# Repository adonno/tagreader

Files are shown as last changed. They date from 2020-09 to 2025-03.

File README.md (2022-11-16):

<a href="https://www.buymeacoffee.com/adonno" target="_blank">Buy Me A Coffee</a>



# Tag Reader for Home Assistant

The tag reader is a simple to build/use NFC tag reader, specially created for [Home Assistant](https://www.home-assistant.io). It is using a D1 mini ESP 8266 and the PN532 NFC module. The firmware is built using [ESPhome](https://www.esphome.io).

> I am selling a pre-built version, a DIY version (assembly required), or just the case (use with own components). Check it out on [my website](https://adonno-crafts.myshopify.com/).

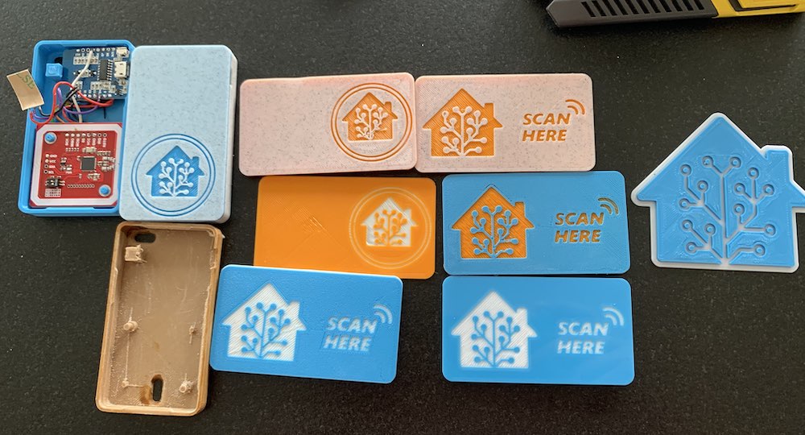
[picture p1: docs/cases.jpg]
Photos of the final product


## Building the tag reader

To build your own tag reader, you need the following components:

 - [ESP8266 D1 Mini](https://s.click.aliexpress.com/e/_d8l72oB)  
 - [PN532 NFC Reader](https://s.click.aliexpress.com/e/_dZNORIJ)
 - [WS2812](https://s.click.aliexpress.com/e/_d82GRqr)
 - [Buzzer](https://s.click.aliexpress.com/e/_dZ5F5yj)

The 3D models for the case are [here](STLs).

~~**WARNING** regarding AZdelivery D1. We have had several users contacting us with different issues, we don't recommend using these boards and won't provide support for them.~~  
Recent reports suggest more clones of the D1 are now working as expected. This has been verified on an AZdelivery D1.

### Connecting the components

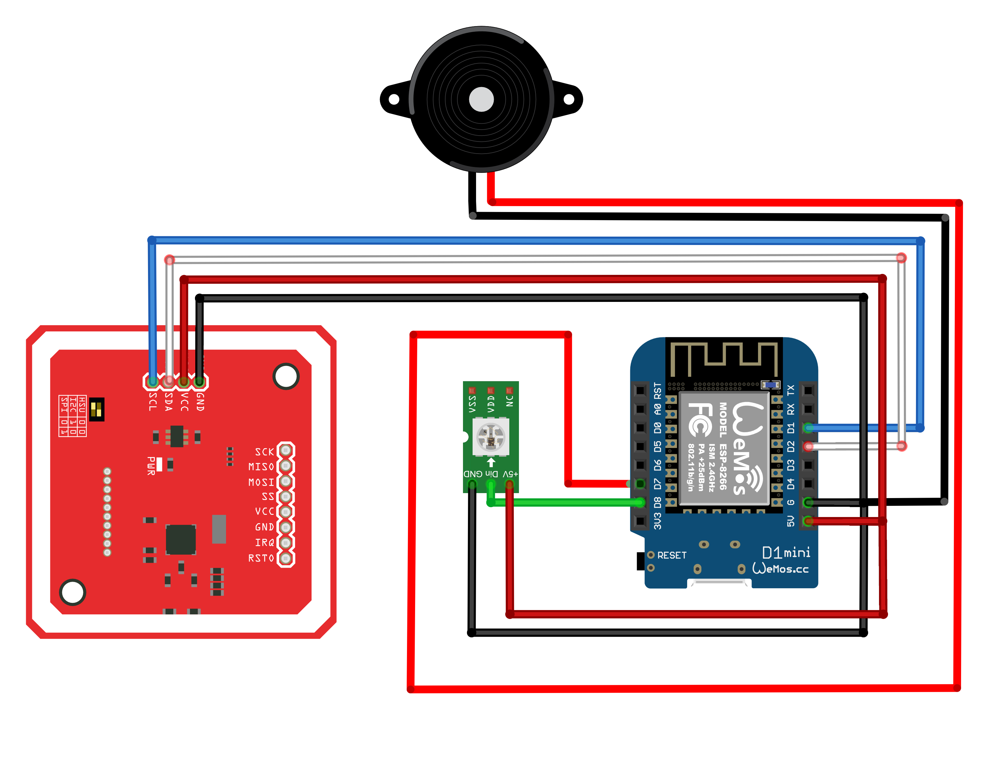
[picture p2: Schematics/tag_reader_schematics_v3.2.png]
Photo of schematics


There are not too many components to connect, but it does require soldering. You will need the following:

- [Solder](https://s.click.aliexpress.com/e/_dT3S62j)
- [Soldering iron with a fairly thin tip](https://s.click.aliexpress.com/e/_dXaI6nz)
- [About 40cm of thin wire (at least 5 different colors)](https://s.click.aliexpress.com/e/_dZvoYoB)

Also, make sure that you have set the switches on the PN532 to the following:
- Switch 1: On (up)
- Switch 2: Off (down)

This enables the PN532 module to communicate with the D1 over I2C, and is required for the modules to work together!

To flash the reader firmware to your D1 Mini you point ESPHome at [tagreader.yaml](tagreader.yaml).  
> :warning: The tag reader requires ESPHome `1.16.0`.

If you're new to ESPHome, we recommend that you use the [ESPHome Home Assistant add-on](https://esphome.io/guides/getting_started_hassio.html).

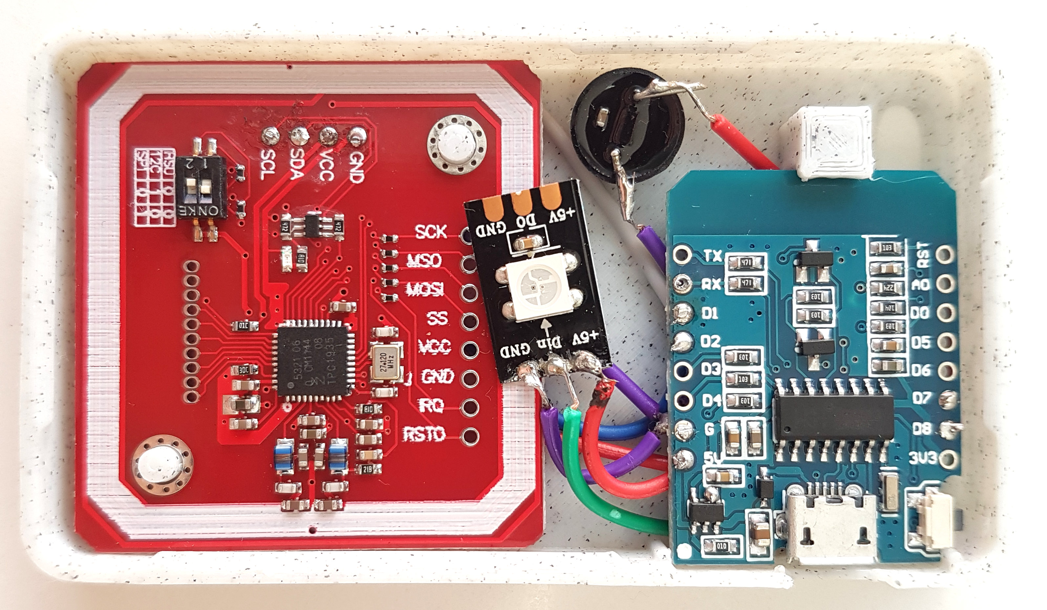
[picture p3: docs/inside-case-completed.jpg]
Open Case


## Configuring for use with Home Assistant

The tag reader requires [Home Assistant](https://www.home-assistant.io) 0.115 or later.

If the tag reader is unable to connect to a wifi network, it will start a WiFi access point with a captive portal to allow you to enter your WiFi credentials.

The tag reader will be automatically discovered by Home Assistant once the tag reader is connected to the same network. You can follow the instructions in the UI to set it up.

## Usage

Scanned tags can be managed from the tags interface in Home Assistant. You can find it under config -> tags.

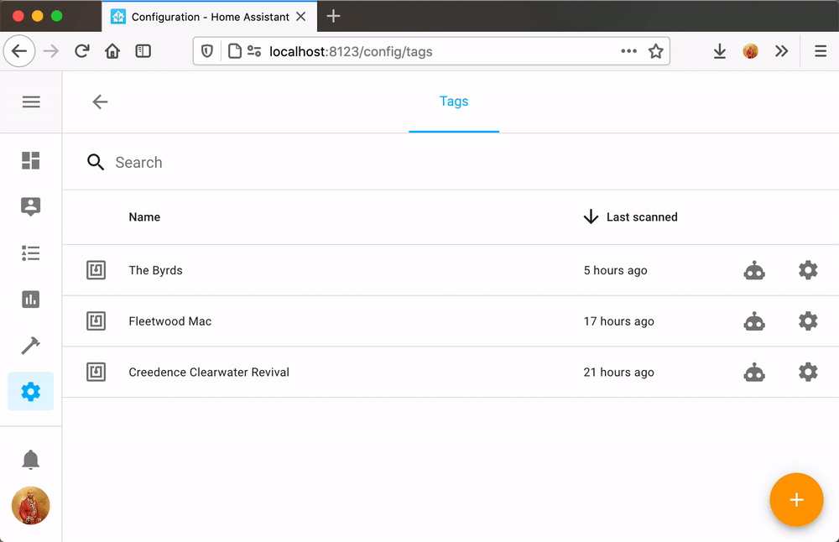
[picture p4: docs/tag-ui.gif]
Screenshot of the Home Assistant tag UI


## Disclamer

We use aliexpress affiliate links for the components and the tools. Some Ad-blockers might block these links and thus they seem to appear broken. You will have to temporarily disable the ad-blocker to open these links.

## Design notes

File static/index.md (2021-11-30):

<a href="https://www.buymeacoffee.com/adonno" target="_blank">Buy Me A Coffee</a>



# Tag Reader for Home Assistant

The tag reader is a simple to build/use NFC tag reader, specially created for [Home Assistant](https://www.home-assistant.io). It is using  the PN532 NFC module. The firmware is built using [ESPhome](https://www.esphome.io).

The Reader works on the 13.56Mhz (NTAG 213) Frequency. 

> You can buy a prebuild version at https://shop.adonno.com

## Installation

You can use the button below to install the firmware directly to your device via USB from the browser.

<esp-web-install-button manifest="./manifest.json"></esp-web-install-button>

<script type="module" src="https://unpkg.com/esp-web-tools@5.2.0/dist/web/install-button.js?module"></script>

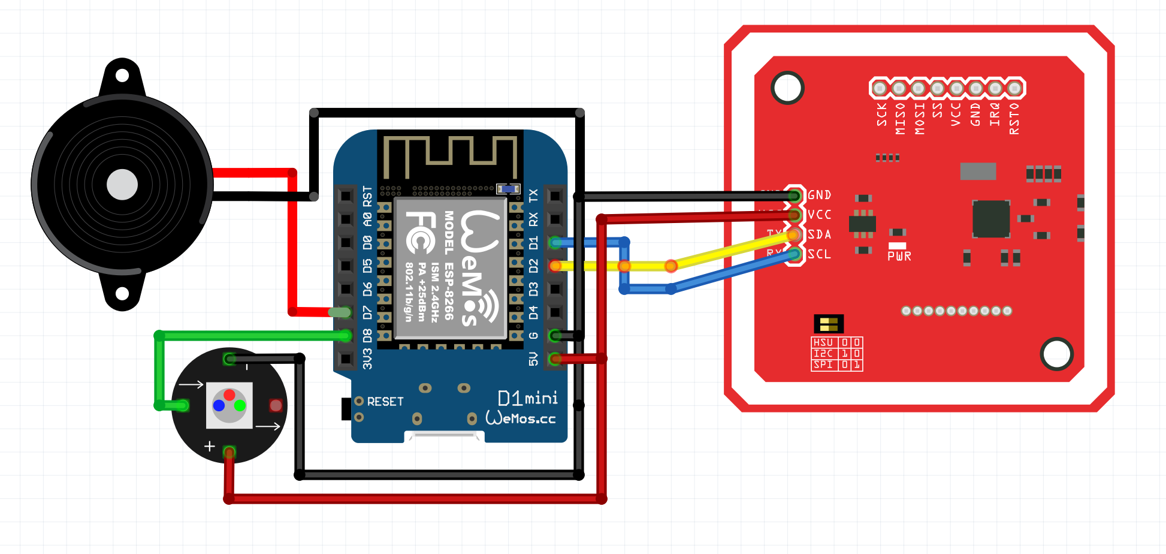
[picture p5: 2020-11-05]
Schematics/tag_reader_schematics_v2.png

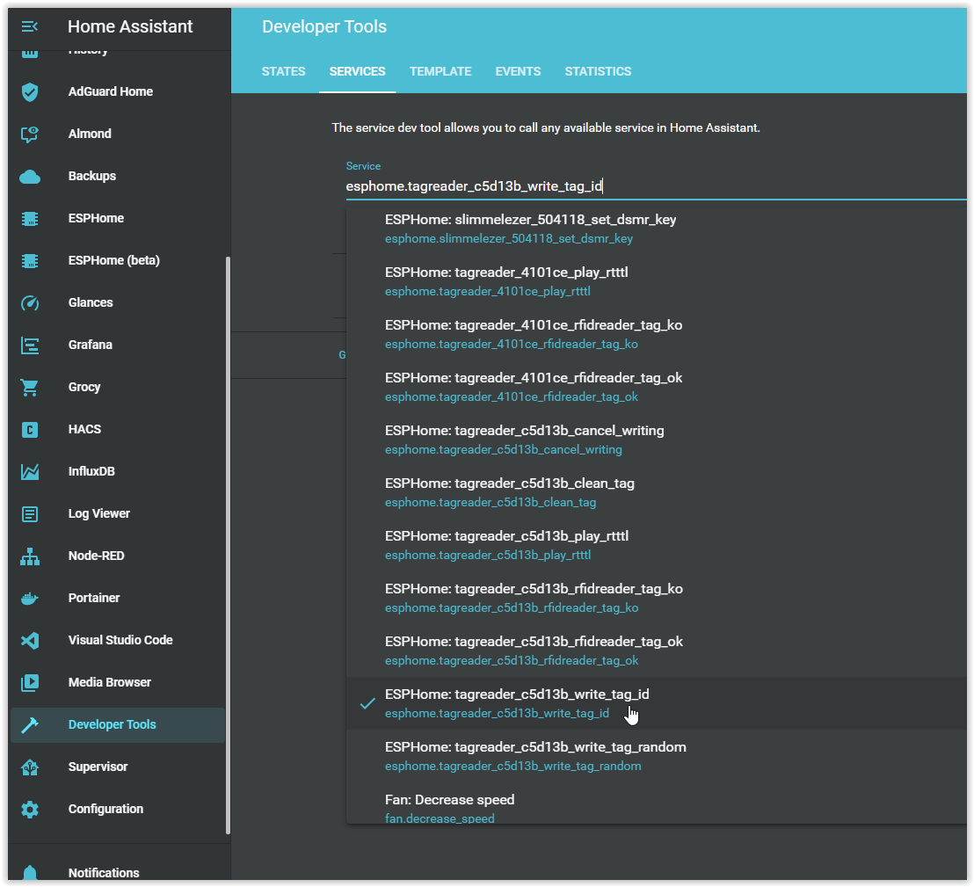
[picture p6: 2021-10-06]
docs/tagreader_services.PNG

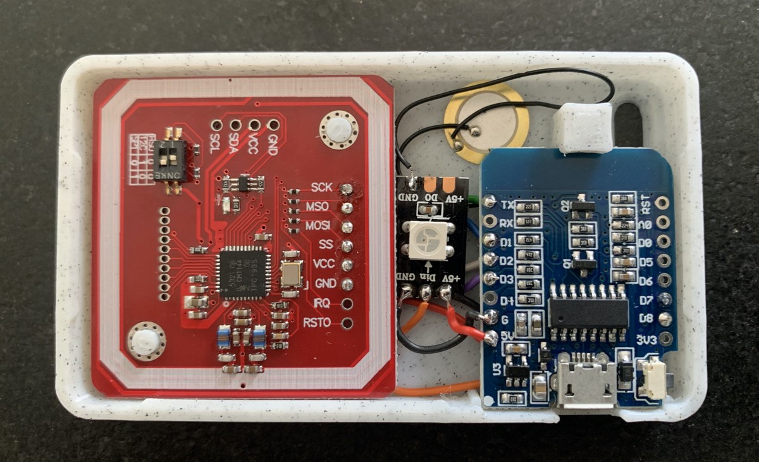
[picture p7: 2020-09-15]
docs/open-case.jpg

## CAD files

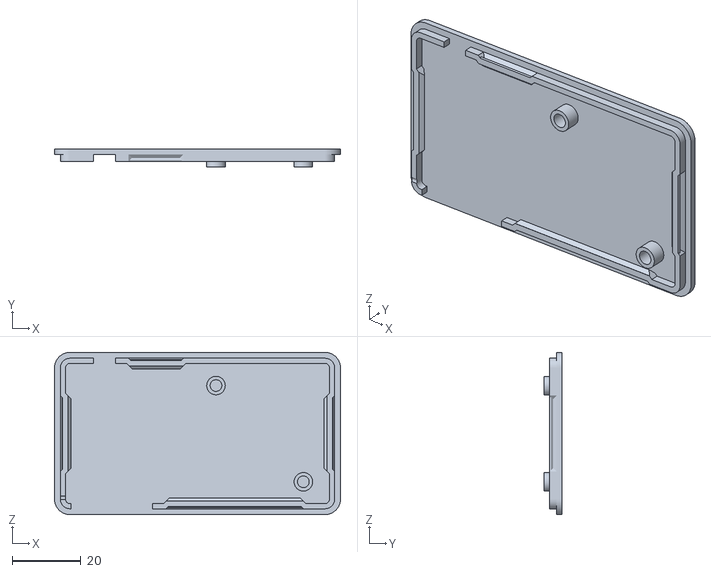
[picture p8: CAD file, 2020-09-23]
STLs/Cover-circles_no_logo.stl
83.2 x 5.10 x 47.2

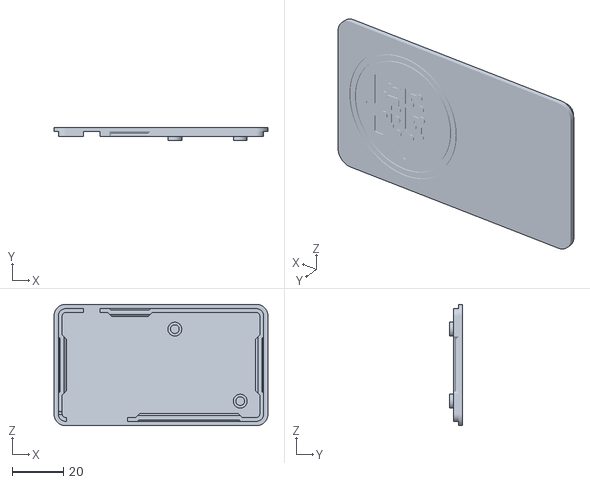
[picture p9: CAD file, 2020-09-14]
STLs/Cover-circles_horizontal.stl
83.2 x 5.10 x 47.2

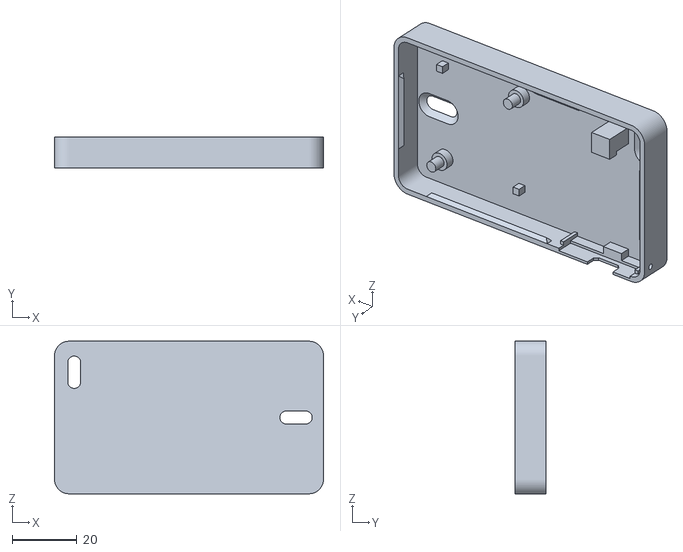
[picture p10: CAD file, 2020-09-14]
STLs/Case-2.stl
83.2 x 9.50 x 47.2

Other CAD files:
STLs/Cover-circles_vertical.stl
STLs/Cover-scan_herel.stl

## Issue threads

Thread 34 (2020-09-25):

D1 Mini won't boot with PN532 power connected

sevlitfest, 2020-09-25:
Initially had same issue on a NodeMCU - then realised it was underpowered for the PN532.
Switched to a D1 Mini - but same, it won't boot to ESP Home when the power is connected.
Boots in fine when Power and GND disconnected - but then obviously can't wake the PN532

Any ideas?

Checked Cables and Pins.

adonno, 2020-09-27:
yeah, we noticed that the PN532 might be messing with the D1. So we (actually @jesserockz ) are currently working on a new version based on I2C that should solve the issue.

lubbertkramer, 2020-09-29:
Any idea for a workaround in the time being?

tdroza, 2020-09-29:
I've been battling with this issue for days! So glad it's not just me! I can see in debug from the D1 that it boots, scans for wifi, attempts to connect then resets the wifi and starts again. Very occasionally it will connect to wifi but then doesn't connect to ESPHome (I'm using the Home Assistant plugin on an RPi 4). I had to remove the `baud:` option from the logger to get log output from the D1 over USB.

I even tried 2 different pn532 boards and about 4 different D1 Minis! I've tried powering the PN532 separately (not from the D1) but get the same issue. I can see tags being scanned in the D1 log output, but obviously Home Assistant doesn't receive an event because the D1 isn't connected. I've stripped down my yaml to remove everything but the SPI and PN532 but no luck. As soon as I disconnect the PN532 the D1 will immediately connect to WiFi.

I considered trying to set it up to use I2C but wasn't sure if it would work. I might give that a go myself while waiting for the updated version.

adonno, 2020-09-29:
@tdroza I2C won't work, for now, @jesserockz is currently working on a new library and is investing a lot of work in this. I would suggest being patient since I don't want to come up with "half" solutions. But yeah we are coming with I2C. SPI is having too many issues and messing with WIFI. I will check with Jessee if we can post a binary for tests

tdroza, 2020-09-29:
Ah ok thanks for the update @adonno. I've got my D1 Mini and PN532 on a breadboard at the moment so if you want me to test any binaries give me a shout as I can change the wiring quickly.

jesserockz, 2020-09-29:
Hello, we have been trying out using I2C, (alongside with some changes to read the NDEF formatted cards that the mobile apps can write to) in #45. You can rewire for I2C and give that PR/branch a try and let us know.
Thanks

sevlitfest, 2020-10-16:
Just tried the new #45 and sadly still have the same issue where ESPHome doesnt seem to boot with the reader connected.
Included the ndef.h and updated the yaml but no joy :(

jesserockz, 2020-10-16:
@sevlitfest can you try #52 please?
Also does it boot if you remove the pn532 lines from yaml, but have the board attached still?

OliPassey, 2020-10-17:
I'm getting errors when trying to compile the new tagreader.yaml in ESPHome.
Using ESPHome 1.15.2
I don't believe im using an AZDelivery D1 Mini - the board has wemos.cc v3.0.0 D1 Mini Printed on it.

When the  ESPHome is first built, with no config and the PN532 connected, it boots fine.

Current compiling error:
`INFO Reading configuration /config/tagreader.yaml...
Failed config

api: [source /config/tagreader.yaml:48]
  services:  [source /config/tagreader.yaml:49]
    - service: rfidreader_tag_ok
      then:
        - rtttl.play: beep:d=16,o=5,b=100:b
    - service: rfidreader_tag_ko
      then:
        - rtttl.play: beep:d=8,o=5,b=100:b
    - service: play_rtttl
      variables:
        song_str: string
      then:
        - rtttl.play: !lambda |-
            return song_str;
    - [source /config/tagreader.yaml:63]
      service: write_tag_random
      variables:
        continuous: bool
      then:  [source /config/tagreader.yaml:67]
        - lambda: id(continous_writing_mode) = continuous;
        - [source /config/tagreader.yaml:68]
          while:  [source /config/tagreader.yaml:69]
            condition:
              lambda: return id(continous_writing_mode);
            then:  [source /config/tagreader.yaml:72]
              - lambda: |-
                  static const char alphanum[] = "0123456789abcdef";
                  std::string uri = "https://www.home-assistant.io/tag/";
                  for (int i = 0; i < 8; i++)
                    uri += alphanum[random_uint32() % (sizeof(alphanum) - 1)];
                  uri += "-";
                  for (int j = 0; j < 3; j++) {
                    for (int i = 0; i < 4; i++)
                      uri += alphanum[random_uint32() % (sizeof(alphanum) - 1)];
                    uri += "-";
                  }
                  for (int i = 0; i < 12; i++)
                    uri += alphanum[random_uint32() % (sizeof(alphanum) - 1)];
                  auto message = new nfc::NdefMessage();
                  message->add_uri_record(uri);
                  ESP_LOGD("tagreader", "Writing payload: %s", uri.c_str());
                  id(pn532_board).write_mode(message);
              - [source /config/tagreader.yaml:89]
        
                Unable to find condition with the name 'pn532.is_writing'.
                wait_until:  [source /config/tagreader.yaml:90]
                  not:
                    pn532.is_writing:
    - service: write_tag_id
      variables:
        tag_id: string
      then:
        - globals.set:
            id: continous_writing_mode
            value: false
        - lambda: |-
            auto message = new nfc::NdefMessage();
            std::string uri = "https://www.home-assistant.io/tag/";
            uri += tag_id;
            message->add_uri_record(uri);
            id(pn532_board).write_mode(message);
    - service: clean_tag
      then:
        - globals.set:
            id: continous_writing_mode
            value: false
        - lambda: id(pn532_board).clean_mode();
    - service: cancel_writing
      then:
        - globals.set:
            id: continous_writing_mode
            value: false
        - lambda: id(pn532_board).read_mode();
pn532_i2c: [source /config/tagreader.yaml:136]

  Component not found: pn532_i2c.
  id: pn532_board
  on_tag:
    then:
      - homeassistant.tag_scanned: !lambda |-
          if (!tag.has_ndef_message()) {
            ESP_LOGD("tagreader", "No NDEF");
            return x;
          }
          auto message = tag.get_ndef_message();
          auto records = message->get_records();
          for (auto &record : records) {
            std::string payload = record->get_payload();
            size_t pos = payload.find("https://www.home-assistant.io/tag/");
            if (pos != std::string::npos) {
              return payload.substr(pos + 34);
            }
          }
          ESP_LOGD("tagreader", "Bad NDEF, fallback to uid");
          return x;
      - if:
          condition:
            switch.is_on: buzzer_enabled
          then:
            - rtttl.play: success:d=24,o=5,b=100:c,g,b
      - if:
          condition:
            switch.is_on: led_enabled
          then:
            - light.turn_on:
                id: activity_led
                brightness: 100%
                red: 0%
                green: 100%
                blue: 0%
                flash_length: 500ms`

OliPassey, 2020-10-17:
I think i've got a USB to Serial UART thing around here somewhere, but not sure if / how it would be any use.
But could i use it to get at logs whilst it's hanging? Or do you already know what the issue may be?

jesserockz, 2020-11-05:
@OliPassey / @sevlitfest Please look at #60 and flash using the esphome `dev` branch

OliPassey, 2020-11-05:
Thanks, i'll give it a test
Much appreciated

OliPassey, 2020-11-05:
@jesserockz - I get further with this one, it boots, i get the buzzer tone as it boots, but it doesnt read any tags.
Nothing in the log other than connected successfully.

INFO Reading configuration /config/tagreader1.yaml...
INFO Starting log output from tagreader1.local using esphome API
INFO Connecting to tagreader1.local:6053 (10.0.0.109)
INFO Successfully connected to tagreader1.local

I'm using ESPHome Dev
Devices have turned up in  HA, LED and Buzzer works but Tag says unavailable.

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

adonno, 2020-11-05:
@OliPassey would you mind taking a picture of your PN532 wiring as well as the jumper settings?

OliPassey, 2020-11-05:
How should the jumper settings be set?
I've tried a few variations, so possibly not in the right position currently.

https://photos.app.goo.gl/roMDHmvJ9qnbHnEe8
Whilst some of the soldering isn't great, i don't have any shorts and all connections are secure.

adonno, 2020-11-05:
Ok please invert the Jumpers
1 on (up)
2 off (down)
restart And you should be fine

OliPassey, 2020-11-05:
Still no joy im afraid.

adonno, 2020-11-05:
What did you flash the ESP with ?
In case you used ESPHome flasher please click on "show logs" while having the D1 connected  and then hit the reset button
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

OliPassey, 2020-11-05:
Using 'COM10' as serial port.
Showing logs:
[14:15:30];d[I][logger:166]: Log initialized
[14:15:30][C][ota:366]: There have been 0 suspected unsuccessful boot attempts.
[14:15:30][I][app:029]: Running through setup()...
[14:15:30][C][esp8266_pwm:017]: Setting up ESP8266 PWM Output...
[14:15:30][C][fastled:010]: Setting up FastLED light...
[14:15:30][C][light:097]: Setting up light 'TagReader1 LED'...
[14:15:30][D][light:265]: 'TagReader1 LED' Setting:
[14:15:30][D][light:278]:   Brightness: 100%
[14:15:30][D][light:287]:   Red=100%, Green=100%, Blue=100%
[14:15:30][C][pn532:027]: Setting up PN532...
[14:15:31][W][i2c:070]: Received NACK on transmit of address 0x24
[14:15:33][W][i2c:086]: Requesting 1 bytes from 0x24 failed!
[14:15:33][E][pn532:031]: Error sending version command
[14:15:33][E][component:092]: Component was marked as failed.
[14:15:33][D][binary_sensor:034]: 'TagReader1 Status': Sending initial state OFF

Just looking to see if i have another reader i can try with.

OliPassey, 2020-11-05:
I dont have another unit to test on, does the above suggest dead hardware or something else?

adonno, 2020-11-06:
Not sure but it means that the D1 isn't communicating with the PN532, check your soldering?  Resolder everything, sometimes it's something really small.
BTW LED and buzzer are not necessary for it to work.

Closed 2020-11-05.

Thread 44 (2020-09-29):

Unstable WiFi connection

tipofthesowrd, 2020-09-29:
The WiFi connection of the esp8266 to the network is unstable.
When connecting the pn532 module and after the setup of the module the WiFi connection and connection to the API stops & hangs often as evidenced by missing pings.

When the module is (physically) connected in HSU mode (or not setup) the connection is stable.

gadgetshed, 2020-09-29:
I can concur that the network connection is very flaky and it seems to drop off the network frequently.

gadgetshed, 2020-09-29:
I'm running a spi and i2c version next to each other and the i2c version is very stable in comparison so it's definitely the way to go.

As an aside the new schematic has the buzzer on D7 but the yaml is on D3 so I'm using D3 for wiring.

tipofthesowrd, 2020-09-29:
Where can I find the i2c version? Esphome didn't seem to have it in the
docs?

Op di 29 sep. 2020 21:14 schreef Steve Cooper <notifications@github.com>:

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

jesserockz, 2020-09-29:
@tipofthesowrd #45

tipofthesowrd, 2020-09-30:
I tried the i2c version, altough I see some improvement, there seem to be some other issues (see below).

As for the WiFi instability, I have the impression it is caused by the proximity of the pn532!!!
I'm using the printed STL files, when Wemos & the PN532 are close to each other the WiFi issues are there.
When I add jumper wires to seperate the boards without the printed housing the connection is stable.

As for the NDEF / I2C version:

Tags written by the Home Assistant Android app are detected either as a NDEF and other times with a UUID.
Example from the same tag read in succession. This causes Home Assistant to detect it as two different tags!
Since the I2C version is not yet official I didn't want to open a seperate issue.

```
[18:28:00][D][ndef_tag_reader:057]: Tag Found!
[18:28:00][D][ndef_tag_reader:102]: No NDEF
[18:28:00][D][ndef_tag_reader:105]: Tag UID: 29-79-7B-9D
[18:28:00][D][text_sensor:015]: 'TagReader Tag': Sending state '29-79-7B-9D'
[18:28:01][D][text_sensor:015]: 'TagReader Tag': Sending state ''
[18:28:42][D][ndef_tag_reader:057]: Tag Found!
[18:28:42][D][ndef_tag_reader:065]: Tag has NDEF
[18:28:42][D][ndef_tag_reader:068]: Tag has 1 records
[18:28:42][D][text_sensor:015]: 'TagReader Tag': Sending state '8d2a73fc-fa4f-4968-8e3e-21e3b4034bbe'
```

adonno, 2020-09-30:
hey @tipofthesowrd what is the brand of this D1 you are using?  We seem to have issues with AZdelivery branded boards

tipofthesowrd, 2020-10-01:
@adonno  Nothing special, they are unbranded, ordered from a local seller for this projet.

I was checking some more and found that when the boards are separated the ping only looses one packet every 10 seconds.
When placed in the housing, almost no ping comes through, except when the PN532 is not setup at boot.

I was looking over the datasheet of the pn532 if there are some RF settings to tweak.

jesserockz, 2020-10-01:
I too have looked over the user guide for the board and could only find the RF on/off command, but nothing to specify power level.

tipofthesowrd, 2020-10-01:
No, I couldn't find anything either. However, there might be something in the way the library operates.

I noticed when reading a tag the ping gets better. I just found this:

```
  if (report) {
    char buf[32];
    format_uid(buf, nfcid, nfcid_length);
    ESP_LOGD(TAG, "Found new tag '%s'", buf);
  }

  this->turn_off_rf_();
```

After reading a tag the RF field is turned off, which might explain why I'm seeing a stable connection for a time after reading a card.

mories76, 2020-10-01:
Hi all,

It looks like I am experiencing the same wifi stability issues with a genuine lolin wemos d1 mini.
The tags read fine, HA is constantly connecting and disconnecting.
The PN532 is connected with a few centimeters of cable.

Later today I will solder some header and use jumper cables and see if the distance between the two have an effect.

mories76, 2020-10-02:
I have to withdraw my last comment ;-)
My wifi was having issues, I was too quick with my with my conclusion.

tipofthesowrd, 2020-10-05:
It might be with my specific type of D1 mini board: it is labeled DOITING.
Reference: https://geekenargentina.wordpress.com/2019/10/08/esp8266-connectivity-troubleshooting/

When touching the antenna, the connection is immediately available. I'll see if I can desolder the tin can and check the capacitor.

tobiasbayer, 2020-10-11:
I can confirm it has something to do with the case or the position of the components inside it. My WiFi connectivity issues disappear as soon as I get the components out of the case and pull the ESP and the PN some (about 5) centimeters apart.

tipofthesowrd, 2020-10-11:
What's the marking on your D1 Mini case? I opened one case and removed the
capacitor as in the reference I linked above.

It's slightly better but still I'm getting serious and regular long
disconnects. I'm waiting for some more to arrive from AliExpress hoping
they're from another manufacturer

Op zo 11 okt. 2020 19:14 schreef Tobias Bayer <notifications@github.com>:

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

tobiasbayer, 2020-10-11:
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

adonno, 2020-10-11:
@tobiasbayer I'd like you to test an Esphome Native I2C based binary  :  [tagreader-i2c.zip](https://github.com/adonno/tagreader/files/5362204/tagreader-i2c.zip)
same goes for everyone else having issues.

**You will have to change the wireing for I2C**
```
D1 --> SCL
D2 --> SDA
```
(please also use GND and VCC from the I2C side)
And do change the Jumper switches on the PN532 for I2C ( 1 Up / 2 Down)

I've been testing for several days and I must admit it works almost flawless (disconnected sometimes due to me moving it around)
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

tipofthesowrd, 2020-10-12:
@adonno I just flashed this verison. I'll report back about my findings.
What's specific about this binary? Anything different the pull request by @jesserockz ?

jesserockz, 2020-10-12:
It's a binary from along the track of #52.
#52 has tag writing as well, but that binary only has reading

tobiasbayer, 2020-10-12:
I flashed the I2C version and did the rewiring. WiFi seems to be pretty stable now.

tipofthesowrd, 2020-10-12:
Same here! This specific binary works great for me as well.

Op ma 12 okt. 2020 13:50 schreef Tobias Bayer <notifications@github.com>:

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

dojf, 2020-10-13:
I flashed the I2C version on a extra ESP8266 D1 Mini and extra PN532 . The difference is big as can be seen in the comparison  below (same timespan). Great work, thank you!

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

Also a very pleasant surprise that the (programmeble) long tags work in this version, thanks!

slemiere, 2020-10-16:
Same effect for me, I was getting disconnects every few minutes and now with the I2C build it's super stable. D1 mini is coming from az-delivery

dartfrogdk, 2020-11-04:
this file seem very stable

apeeters, 2020-11-24:
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

I was the one who added that line in an attempt to get a more stable WiFi connection. I now moved to the pn532_i2c version which is WAY more stable, great work!

Closed 2020-11-05.

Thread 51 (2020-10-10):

NFC Tags not read

tobiasbayer, 2020-10-10:
My setup does not read any NFC Tags. They simply do not show up in the "Tags" view in HA when I place them near the reader.
Bascially, the communication between the ESP and HA seems to work ok as I can turn on and off the LED via the Lovelace UI.
The PN532 seems to be powered on at least as the red LED is constantly on.

Any hints on how I could debug this?

mories76, 2020-10-10:
Do you have access to the console of the ESP ?
The console reports whether the PN532 can be found or not.

Also how did you connect your PN532 ?
spi, i2c. The dipswitches on the PN532 should be set accordingly

tobiasbayer, 2020-10-10:
I wired it up like shown [here](https://github.com/adonno/tagreader#connecting-the-components) and set the dip switches accordingly.
I'll try to get access to the console and will report back here.

tobiasbayer, 2020-10-10:
I got this output:

`...
 [0;35m[C][spi:081]: SPI bus: [0m
 [0;35m[C][spi:082]:   CLK Pin: GPIO16 (Mode: OUTPUT) [0m
 [0;35m[C][spi:083]:   MISO Pin: GPIO5 (Mode: INPUT) [0m
 [0;35m[C][spi:084]:   MOSI Pin: GPIO4 (Mode: OUTPUT) [0m
 [0;35m[C][spi:085]:   Using HW SPI: NO [0m
...
 [0;35m[C][pn532:355]: PN532: [0m
 [0;35m[C][pn532:367]:   CS Pin: GPIO0 (Mode: OUTPUT) [0m
 [0;35m[C][pn532:368]:   Update Interval: 2.0s [0m
 [0;35m[C][rtttl:017]: Rtttl [0m
...
 [0;36m[D][api.connection:604]: Client 'Home Assistant 0.116.2 (192.168.178.111)' connected successfully! [0m
 [0;36m[D][rtttl:093]: Playback finished [0m
 [0;32m[I][ota:046]: Boot seems successful, resetting boot loop counter. [0m
`

mories76, 2020-10-10:
What happens when you offer a tag, do you see anything happening on the console ?
It should include something like below, depend on the version of pn532 integration your running.
[16:00:17][D][pn532:150]: Found tag '04-7A-CC-1A-F5-48-80'

Do you have different tags available ? Can you scan the tag with your phone, with a tool something like NFC Tools.
I have one type of tags which isn't read yet with the firmware I am running. Mifare Ultralight

tobiasbayer, 2020-10-10:
Ok, it now worked and shortly stopped working after I moved the reader and worked again after moving it some more. I suspect some sort of bad soldering or something like that. I'll redo the soldering.
Thanks a lot for your help debugging this!

RosaEinhorn, 2021-02-23:
Hello, I have the same problem. Tags are not read and I am getting
```
[10:23:57][W][i2c:070]: Received NACK on transmit of address 0x24
[10:23:58][W][i2c:086]: Requesting 1 bytes from 0x24 failed!
[10:23:58][E][pn532:019]: Error sending version command
```
in the logs.

The soldering is not perfect, but it should work (see pictures).

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

Would appreciate any help. :)

Closed 2020-10-10.

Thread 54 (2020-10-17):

No scan after a few minutes

dcjona, 2020-10-17:
Hi,

I made the prototype and test it. everything is ok but after a few minutes i hear the buzzer and then no more scan can be done.
Like if it shutdown ou hibernate...

I have to launch the show logs on esphome flasher to wake up ... else nothing works

Could you help ?

jesserockz, 2020-10-18:
Hi @dcjona

We are going to need more information than that to be able to help...
The only way to know what is going on, is to reproduce the issue while watching the serial logs, otherwise there is no way t know what is happening.

Jesse

dcjona, 2020-10-21:
Hello, i made another module and same issue..

i don"t know why when i power off esphome flasher the tag reader doesn't works anymore...

jesserockz, 2020-10-22:
Thanks @dcjona can you try using the instructions, code and wiring configuration in #52?

The wake up failed is a bit of a weird error with the current pn532 code and I have a branch in esphome which gives it a few upgrades and more reliability.

dcjona, 2020-11-26:
thqnk you @jesserockz sorry for the delay i will try

seranoo, 2021-05-10:
I have had issues with the i2c communication failing after a few minutes. Got a read error, only thing to do was to power cycle the ESP.

I was initially using a Wuqiong ESP-WROOM-32 (https://www.amazon.se/gp/product/B086ZQ7TL5/ref=ppx_yo_dt_b_asin_title_o07_s00?ie=UTF8&psc=1), i.e. this was the ESP that I had the above issues with.

I then changed to a
WEMOS/LOLIN D1 mini v3.1.0 (https://www.m.nu/esp8266/d1-mini-v310) and now everything works perfectly. It has now been running for a couple of days, no issues. I read somewhere that it potentially could be some issue with "missing" pullup resistors on the i2c GPIOs, haven't tested that yet.

BTW, I use a PN532 from here: https://www.amazon.se/gp/product/B0919BP156/ref=ppx_yo_dt_b_asin_title_o03_s00?ie=UTF8&psc=1

I run the setup without the buzzer and the LED, works super nice!

Closed 2021-09-17.

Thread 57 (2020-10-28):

STL printing in two colors

chadlyy, 2020-10-28:
Do you have any recommendations on how to print your STLs in 2 colors? It looks like I need 2 parts to merge.  Sorry, I'm really new to 3d printing, any help would be really appreciated!

zuidwijk, 2020-10-28:
you can try this way: https://youtu.be/1nBnVtOEAiY

zuidwijk, 2020-10-28:
I'm printing a case myself too. And just printed case (bottom part). Tomorrow I'll try to print the top cover in two colors the way shown in the video.

zuidwijk, 2020-10-29:
Ok I tried two ways:

1) as described in the youtube video. That didn't work. It paused and after 1 second resumed immediately. These are my settings: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
2) used the filament change script (M600 code). That didn't work on my CR-6 SE.

So for me, I'm still searching for the right way. For now I've got two white covers.
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

adonno, 2020-10-30:
Hello I used that exact same Video but I also Use octoprint
I am using an Ender5 Pro

zuidwijk, 2020-10-31:
> Hello I used that exact same Video but I also Use octoprint
>
> I am using an Ender5 Pro

For the Ender it's supported, yet for the CR-6 SE not, unfortunately.

zuidwijk, 2020-11-01:
Not tried yet, but the right code should me M25. You can modify the code and change M0 to M25, you can also add it like this:
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
````
;TIME_ELAPSED:816.988185
;TYPE:CUSTOM
;added code by post processing
;script: PauseAtHeight.py
;current layer: 2
M83 ; switch to relative E values for any needed retraction
G1 F3000 E-25
G1 F300 Z1.6 ; move up a millimeter to get out of the way
G1 F9000 X20 Y20
G1 F300 Z15 ; too close to bed--move to at least 15mm
M104 S25 ; standby temperature
M0 ; Do the actual pause
M25
M109 S200 ; resume temperature
G1 F3000 E25
G1 F3000 E-25
G1 F300 Z1.6
G1 F9000 X106.468 Y74.537
G1 F300 Z0.6 ; move back down to resume height
G1 F3000 E25
G1 F1500 ; restore extrusion feedrate
M82 ; switch back to absolute E values
G92 E499.70827
````
More explained here: https://www.youtube.com/watch?v=mnujJOvzf0o

zuidwijk, 2020-11-01:
Ok just tried it. It works... but you've got to be careful. The change of filament didn't went that smooth and when started printing, the 2nd change (back to white) made a big blob of filament which I could peel away with tweezers just before the nozzle printed again in the same area. 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

adonno, 2020-11-01:
I avoid them by staying there and pull the blob with the tweezers

Closed 2020-11-20.

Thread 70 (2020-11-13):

" Timed out waiting for readiness from PN532!"

sirvictory444, 2020-11-13:
Hello,
Changing the logger level to VERBOSE I can see the error message:  "Timed out waiting for readiness from PN532!"
If I use VERY_VERBOSE I can see "A component took a long time in a loop() cycle"
Card reads do not work.  If I hold the card over the NFC sensor for 5-10 seconds, eventually a read will come in.
I've double checked the wiring, proper soldering, etc, thats not an issue.   I know the i2c version of this is still in the dev mode.
Do I have a bad board? I've tried with 2 different D1 minis, but only have the 1 PN532.
The hardware is in the 3d printed case from this repo.
My ESP board does not say AZ Delivery.
Thank You,

RichieFrame, 2020-11-14:
Could be a bad reader board, I had 1 out of 3 not work out of the box, I was able to trace it to bad solder flow which joined 2 of the independent circuits on the board, because a component was off center by about 0.25mm when it was surface mount soldered

adonno, 2020-11-14:
In this case it's the firmware
I would suggest using the newest yaml in combination with ESPHome dev as explained on the Readme.md you'll have to resolder to I2C instead of SPI but it will run rock solid

sirvictory444, 2020-11-14:
> In this case it's the firmware
> I would suggest using the newest yaml in combination with ESPHome dev as explained on the Readme.md you'll have to resolder to I2C instead of SPI but it will run rock solid

Yes, this is with I2C.  Using the latest firmware yaml, wiring, and dev version of ESPHome.   SDA & SCL wiring.  I suppose I'll order another board if you're saying it's not a software issue?

adonno, 2020-11-14:
last question are the Jumpers set correctly?

sirvictory444, 2020-11-14:
> last question are the Jumpers set correctly?

Yes, I0 on/up, I1 off/down.     Like I said, it does work once every 30 seconds maybe, in between getting random mismatched data.  I don't think it would do that unless it was set correct, no?  Maybe DIP switch is bad, I've seen that with even the larger through hole kind.  I'll try to use some thin wire to solder them, if I'm able to without messing it up.

sirvictory444, 2020-11-15:
I ordered another board.  I suppose we can close this ticket, as we're saying it's probably a hardware issue.

Closed 2020-11-15.

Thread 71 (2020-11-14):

Trigger the buzzer (with custom sounds) and / or set the light (with color) from HA

Mincka, 2020-11-14:
I just received my tag reader today. Thank you for this great project! 👍

I would like to know if you think it could be possible to use the Notify platform / a Service in HA to send specific commands to the device.
I think it could be great to be able make it beep with custom music notes that you could send as a message, or to use its LED as a light in HA.

Since the idea is to have this device bound to a room, I would use this to make distinct sounds to warn me about specific events or status.

A few ideas:
- Warning beep + red flash if I open the door to leave but some windows are open
- When I come home (based on motion sensor), the device beeps differently (or light up with a specific color) to tell me if my wife has already left her work or not.
- Reply based on status (1): I flash a badge to request a binary status, the reader answers with yes / no sound + green / red light.
- Reply based on status (2): I flash a badge to request the weather and the tag reader answers (from automation) with a color code (eg. red for rain, orange for chance of rain, white for snow, yellow for sunny...).
- Permanent light that changes color based on a associated sensor (e.g. ambient air status from green to red)

RichieFrame, 2020-11-14:
All these features already exist in the code. The LED is already reported as a light in HA, you can do all the normal stuff with it, although the brightness cannot go below somewhere around 18% due to limitations with the chipset pwm and the LED frequency, using a different LED on ESP32 with LEDC output allows it to go lower.

As for using the buzzer, the service is available in HA as ```esphome.tagreader_play_rtttl```

For alert notifications, I have already integrated the device into my alert flow, which is colored based on the type/severity of alert. Blue (general notification 1), Green (general notification 2), Yellow (alert, maybe you should look into it), Orange (alert, you should look into it now), Red (alert, danger)

adonno, 2020-11-14:
I didn't think about it but I really like this especially since I'm thinking about a more "enhanced" version once I get everything delivered

Mincka, 2020-11-14:
Thank you @RichieFrame! Next time, I will dig deeper before submitting "issues". I am very new to ESPHome. The platform looks like very powerful.

Indeed, it looks like I can already answer to all my ideas with your input. I will check tomorrow and close this issue.

Maybe it could be useful to highlight a bit more these "indirect" features of the tag reader.

Mincka, 2020-11-15:
I tried to change the colors of the LED, it worked but at some point, the device became unavailable.
I needed to reboot it a few times to get it back available in HA, very strange. I tried to reproduce but didn't manage to.

For the buzzer, it works perfectly with the play_rttl service and a song_str string
`song_str: "McGyver:d=4,o=4,b=160:8c5,8c5,8c5,8c5,2b,8f#,a,2g,8c5,c5,b,8a,8b,8a,g,e5,2a,b.,8p,8c5,8b,8a,c5,8b,8a,d5,8c5,8b,d5,8c5,8b,e5,8d5,8e5,f#5,b,1g5,8p,8g5,8e5,8c5,8f#5,8d5,8b,8e5,8c5,8a,8d5,8b,8g,c5,b,8c5,8b,8a,8g,a#,a,8g."`

I'm just putting this here as reference:
https://esphome.io/components/rtttl.html

😍

Closed 2020-11-15.

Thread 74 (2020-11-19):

Piezo buzzer volume is too low | INFO

CarpeDiemRo, 2020-11-19:
There is any possibility to increase the volume of the piezo buzzer?

RichieFrame, 2020-11-20:
I am using an actively powered passive buzzer, it takes constant 3.3v input plus the 3,3v trigger from the ESP GPIO... it is quite loud. You can even add a potentiometer to the ground for a volume knob, I am using a 470ohm resistor to get appropriate volume for an open air design

CarpeDiemRo, 2020-11-20:
> I am using an actively powered passive buzzer, it takes constant 3.3v input plus the 3,3v trigger from the ESP GPIO... it is quite loud. You can even add a potentiometer to the ground for a volume knob, I am using a 470ohm resistor to get appropriate volume for an open air design

I have an active buzzer, too and it works perfectly. The major problem is that is too big and it is not fit into adonno box.

adonno, 2020-11-20:
there is someone who drilled a hole in the case to fit the Buzzer ,  unfortunately considering that we wanted to have a slim design we had to revert to this buzzer. Function follows form :-D

Closed 2020-11-22.

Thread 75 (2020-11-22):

No NFC Tag is reading

ollimagic, 2020-11-22:
I Build everything like in the description but no tag arrived in Home Assistant NFC
i add tham vie Mobile but nothing happen when i use tham on the reader

dmeus, 2020-11-22:
Likewise, would love to learn how to fix this.

adonno, 2020-11-22:
Would you mind sending me a picture of the "Reader? " are the Jumpers correct?
(1 up  2 Down)

dmeus, 2020-11-22:
> Would you mind sending me a picture of the "Reader? " are the Jumpers correct?
> (1 up 2 Down)

Atm they are 1 down, 2 up as stated in the readme? Connection to my network works (d1 has an ip adress) and home assistant discovered 4 entities. At least so far so good. No dice on recognising a tag tho... in the esphome log it also only states ‘api connected’, no further log. Is that normal?

adonno, 2020-11-22:
They have to be 1UP 2DOWN

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

That should solve the issue

ollimagic, 2020-11-22:
i guess i did everything like on your picture

Am So., 22. Nov. 2020 um 17:30 Uhr schrieb Andrea Donno <
notifications@github.com>:

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

ollimagic, 2020-11-22:
yes the reader appears in hassio

Am So., 22. Nov. 2020 um 17:39 Uhr schrieb Olli Boe <ollimagic@gmail.com>:

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

ollimagic, 2020-11-22:
INFO Reading configuration /config/esphome/Tag2.yaml...
INFO Starting log output from tagreader.local using esphome API
INFO Connecting to tagreader.local:6053 (192.168.178...)
INFO Successfully connected to tagreader.local
[17:42:44][I][app:105]: ESPHome version 1.16.0-dev compiled on Nov 22
2020, 16:28:28
[17:42:44][C][wifi:443]: WiFi:......
[17:42:44][C][wifi:303]:   SSID: ....
[17:42:44][C][wifi:304]:   IP Address: 192.168.178...
[17:42:44][C][wifi:306]:   BSSID: [redacted]
[17:42:44][C][wifi:307]:   Hostname: 'tagreader'
[17:42:44][C][wifi:311]:   Signal strength: -48 dB ▂▄▆█
[17:42:44][C][wifi:315]:   Channel: 1
[17:42:44][C][wifi:316]:   Subnet: 255.255.255.0
[17:42:44][C][wifi:317]:   Gateway: 192.168.178.1
[17:42:44][C][wifi:318]:   DNS1: 192.168.178.1
[17:42:44][C][wifi:319]:   DNS2: (IP unset)
[17:42:44][C][i2c:028]: I2C Bus:
[17:42:44][C][i2c:029]:   SDA Pin: GPIO4
[17:42:44][C][i2c:030]:   SCL Pin: GPIO5
[17:42:44][C][i2c:031]:   Frequency: 400000 Hz
[17:42:44][C][template.switch:058]: Template Switch 'TagReader Buzzer Enabled'
[17:42:44][C][template.switch:058]:   Icon: 'mdi:volume-high'
[17:42:44][C][template.switch:059]:   Restore State: NO
[17:42:44][C][template.switch:060]:   Optimistic: YES
[17:42:44][C][template.switch:058]: Template Switch 'TagReader LED enabled'
[17:42:44][C][template.switch:058]:   Icon: 'mdi:alarm-light-outline'
[17:42:44][C][template.switch:059]:   Restore State: NO
[17:42:44][C][template.switch:060]:   Optimistic: YES
[17:42:44][C][esp8266_pwm:022]: ESP8266 PWM:
[17:42:44][C][esp8266_pwm:023]:   Pin: GPIO13 (Mode: OUTPUT)
[17:42:44][C][esp8266_pwm:024]:   Frequency: 988.0 Hz
[17:42:44][C][fastled:019]: FastLED light:
[17:42:44][C][fastled:020]:   Num LEDs: 1
[17:42:44][C][fastled:021]:   Max refresh rate: 400
[17:42:44][C][logger:185]: Logger:
[17:42:44][C][logger:186]:   Level: DEBUG
[17:42:44][C][logger:187]:   Log Baud Rate: 115200
[17:42:44][C][logger:188]:   Hardware UART: UART0
[17:42:44][C][light:178]: Light 'TagReader LED'
[17:42:44][C][light:180]:   Default Transition Length: 0.0s
[17:42:44][C][light:181]:   Gamma Correct: 2.80
[17:42:44][C][pn532:321]: PN532:
[17:42:44][C][pn532:333]:   Update Interval: 1.0s
[17:42:44][C][pn532_i2c:041]:   Address: 0x24
[17:42:44][C][status:034]: Status Binary Sensor 'TagReader Status'
[17:42:44][C][status:034]:   Device Class: 'connectivity'
[17:42:44][C][rtttl:017]: Rtttl
[17:42:44][C][captive_portal:169]: Captive Portal:
[17:42:44][C][ota:029]: Over-The-Air Updates:
[17:42:44][C][ota:030]:   Address: tagreader.local:8266
[17:42:44][C][api:095]: API Server:
[17:42:44][C][api:096]:   Address: tagreader.local:6053

dmeus, 2020-11-22:
Tried switching the -well- switches (given that I first set them as pictured in the readme), still nothing. They are now in this position: according to my understanding 1 is in the up position now?

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

When I try to access the logs in esphome-dev, the logger shows nothing after ‘INFO Successfully connected to tagreader.local’. I’m guessing this is a red herring...

adonno, 2020-11-22:
Would you mind checking your solders?  SDA seems a bit "bad"
Could you please also post a picture from your D1 as well?

In addition, maybe try checking directly with the ESP connected to your PC and getting the logs via USB by using ESPHome flasher  https://github.com/esphome/esphome-flasher/releases
Connect the ESP to your pc and select the right com port and hit view logs

ollimagic, 2020-11-23:
hi i tried everything different boards different cable but nothing how can
i log if something happen on the reader
in esplog i see that
[0;36m[D][wifi:339]: Found networks: [0m
[0;32m[I][wifi:385]: - 'FritzBox' [5m(2C:91:AB:96:80:23) [6m
[0;33mÔûéÔûäÔûå [0;37mÔûê [0m [0m
[0;36m[D][wifi:386]:     Channel: 1 [0m
[0;36m[D][wifi:387]:     RSSI: -59 dB [0m
[0;32m[I][wifi:385]: - 'FritzBox' [5m(5C:49:79:FE:E4:DB) [6m [0;33mÔûéÔûä
[0;37mÔûåÔûê [0m [0m
[0;36m[D][wifi:386]:     Channel: 6 [0m
[0;36m[D][wifi:387]:     RSSI: -71 dB [0m
[0;32m[I][wifi:385]: - 'FritzBox' [5m(98:9B:CB:56:73:6D) [6m [0;33mÔûéÔûä
[0;37mÔûåÔûê [0m [0m
[0;36m[D][wifi:386]:     Channel: 6 [0m
[0;36m[D][wifi:387]:     RSSI: -73 dB [0m
[0;36m[D][wifi:389]: - [5m'1xxBox' [6m [5m(44:4E:6D:28:0E:19) [6m
[0;33mÔûéÔûäÔûå [0;37mÔûê [0m [0m
[0;36m[D][wifi:389]: - [5m'xxZugang' [6m [5m(2E:91:AB:96:80:23) [6m
[0;33mÔûéÔûäÔûå [0;37mÔûê [0m [0m
[0;36m[D][wifi:389]: - [5m'' [6m [5m(B6:7C:9C:DC:A5:9A) [6m [0;33mÔûéÔûä
[0;37mÔûåÔûê [0m [0m
[0;36m[D][wifi:389]: - [5m'MieterZugang' [6m [5m(5E:49:79:FE:E4:DB) [6m
[0;33mÔûéÔûä [0;37mÔûåÔûê [0m [0m
[0;36m[D][wifi:389]: - [5m'FritzMa' [6m [5m(E8:94:F6:59:2C:01) [6m
[0;33mÔûéÔûä [0;37mÔûåÔûê [0m [0m
[0;36m[D][wifi:389]: - [5m'FritzMa' [6m [5m(E8:94:F6:59:38:B2) [6m
[0;33mÔûéÔûä [0;37mÔûåÔûê [0m [0m
[0;36m[D][wifi:389]: - [5m'FritzMa' [6m [5m(38:10:D5:36:59:C5) [6m
[0;33mÔûéÔûä [0;37mÔûåÔûê [0m [0m
[0;36m[D][wifi:389]: - [5m'FritzMa' [6m [5m(F4:F2:6D:F5:E3:1D) [6m
[0;31mÔûé [0;37mÔûäÔûåÔûê [0m [0m
[0;32m[I][wifi:194]: WiFi Connecting to 'FritzBox'... [0m
[0;32m[I][wifi:457]: WiFi Connected! [0m
[0;35m[C][wifi:303]:   SSID: [5m'FritzBox' [6m [0m
[0;35m[C][wifi:304]:   IP Address: 192.168.178.83 [0m
[0;35m[C][wifi:306]:   BSSID: [5m2C:91:AB:96:80:23 [6m [0m
[0;35m[C][wifi:307]:   Hostname: 'tagreader' [0m
[0;35m[C][wifi:311]:   Signal strength: -51 dB [0;33mÔûéÔûäÔûå [0;37mÔûê
[0m [0m
[0;35m[C][wifi:315]:   Channel: 1 [0m
[0;35m[C][wifi:316]:   Subnet: 255.255.255.0 [0m
[0;35m[C][wifi:317]:   Gateway: 192.168.178.1 [0m
[0;35m[C][wifi:318]:   DNS1: 192.168.178.1 [0m
[0;35m[C][wifi:319]:   DNS2: (IP unset) [0m
[0;36m[D][wifi:466]: Disabling AP... [0m
[0;35m[C][ota:029]: Over-The-Air Updates: [0m
[0;35m[C][ota:030]:   Address: tagreader.local:8266 [0m
[0;35m[C][api:022]: Setting up Home Assistant API server... [0m
[0;32m[I][app:059]: setup() finished successfully! [0m
[0;32m[I][app:105]: ESPHome version 1.16.0-dev compiled on Nov 22 2020,
16:28:28 [0m
[0;35m[C][wifi:443]: WiFi: [0m
[0;35m[C][wifi:303]:   SSID: [5m'FritzBox' [6m [0m
[0;35m[C][wifi:304]:   IP Address: 192.168.178.83 [0m
[0;35m[C][wifi:306]:   BSSID: [5m2C:91:AB:96:80:23 [6m [0m
[0;35m[C][wifi:307]:   Hostname: 'tagreader' [0m
[0;35m[C][wifi:311]:   Signal strength: -52 dB [0;33mÔûéÔûäÔûå [0;37mÔûê
[0m [0m
[0;35m[C][wifi:315]:   Channel: 1 [0m
[0;35m[C][wifi:316]:   Subnet: 255.255.255.0 [0m
[0;35m[C][wifi:317]:   Gateway: 192.168.178.1 [0m
[0;35m[C][wifi:318]:   DNS1: 192.168.178.1 [0m
[0;35m[C][wifi:319]:   DNS2: (IP unset) [0m
[0;35m[C][i2c:028]: I2C Bus: [0m
[0;35m[C][i2c:029]:   SDA Pin: GPIO4 [0m
[0;35m[C][i2c:030]:   SCL Pin: GPIO5 [0m
[0;35m[C][i2c:031]:   Frequency: 400000 Hz [0m
[0;35m[C][template.switch:058]: Template Switch 'TagReader Buzzer Enabled'
[0m
[0;35m[C][template.switch:058]:   Icon: 'mdi:volume-high' [0m
[0;35m[C][template.switch:059]:   Restore State: NO [0m
[0;35m[C][template.switch:060]:   Optimistic: YES [0m
[0;35m[C][template.switch:058]: Template Switch 'TagReader LED enabled' [0m
[0;35m[C][template.switch:058]:   Icon: 'mdi:alarm-light-outline' [0m
[0;35m[C][template.switch:059]:   Restore State: NO [0m
[0;35m[C][template.switch:060]:   Optimistic: YES [0m
[0;35m[C][esp8266_pwm:022]: ESP8266 PWM: [0m
[0;35m[C][esp8266_pwm:023]:   Pin: GPIO13 (Mode: OUTPUT) [0m
[0;35m[C][esp8266_pwm:024]:   Frequency: 1000.0 Hz [0m
[0;35m[C][fastled:019]: FastLED light: [0m
[0;35m[C][fastled:020]:   Num LEDs: 1 [0m
[0;35m[C][fastled:021]:   Max refresh rate: 400 [0m
[0;35m[C][logger:185]: Logger: [0m
[0;35m[C][logger:186]:   Level: DEBUG [0m
[0;35m[C][logger:187]:   Log Baud Rate: 115200 [0m
[0;35m[C][logger:188]:   Hardware UART: UART0 [0m
[0;35m[C][light:178]: Light 'TagReader LED' [0m
[0;35m[C][light:180]:   Default Transition Length: 0.0s [0m
[0;35m[C][light:181]:   Gamma Correct: 2.80 [0m
[0;35m[C][pn532:321]: PN532: [0m
[0;35m[C][pn532:333]:   Update Interval: 1.0s [0m
[0;35m[C][pn532_i2c:041]:   Address: 0x24 [0m
[0;35m[C][status:034]: Status Binary Sensor 'TagReader Status' [0m
[0;35m[C][status:034]:   Device Class: 'connectivity' [0m
[0;35m[C][rtttl:017]: Rtttl [0m
[0;35m[C][captive_portal:169]: Captive Portal: [0m
[0;35m[C][ota:029]: Over-The-Air Updates: [0m
[0;35m[C][ota:030]:   Address: tagreader.local:8266 [0m
[0;35m[C][api:095]: API Server: [0m
[0;35m[C][api:096]:   Address: tagreader.local:6053 [0m
[0;36m[D][main:119]: API is connected! [0m
[0;36m[D][rtttl:037]: Playing song success [0m
[0;36m[D][light:265]: 'TagReader LED' Setting: [0m
[0;36m[D][light:274]:   State: ON [0m
[0;36m[D][light:278]:   Brightness: 100% [0m
[0;36m[D][light:287]:   Red=0%, Green=0%, Blue=100% [0m
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
ollimagic, 2020-11-23:
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

ollimagic, 2020-11-23:
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
![Uploading 20201122_173642.jpg…]()

ollimagic, 2020-11-23:
the connectors are all working i testet tham

ollimagic, 2020-11-23:
i mean the solder points have all connection sorry for my english

adonno, 2020-11-23:
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

Please invert the switchtes and retry

ollimagic, 2020-11-23:
now ist is working i change the nfc reade board again hurraaaaaaaaaaaaaaaaaaaaaaaaaaaaaaaaaaaaaaaa

ollimagic, 2020-11-23:
sorry for wasting your time i guess my boad was defect

dmeus, 2020-11-23:
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

I have double checked the solders and they are transferring a signal between the D1 and PN532. This works for both SDA and SCL. Photo of the D1 below. When I hook the device up to my laptop, open the logs in ESPHome Flasher and hold an NFC card against the reader it recognizes the tags.

[19:39:43][D][pn532:159]: Found new tag '04-2B-5C-EA-B3-6D-80'
[19:39:49][D][pn532:159]: Found new tag '04-2C-5F-EA-B3-6D-80'

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

dmeus, 2020-11-24:
OK, I deleted the node in ESPHome and compiled a new firmware. Flashed it to the D1, filled in wifi details via the captive portal and rebooted the whole thing. Same scenario as above. ESPHome shows no logs for the node except 'connected', ESPHome flasher shows everything as stated above when I open the node in HA. Tags are recognized by ESPHome Flasher when I present them but they trigger no automation. I can't for the life of me figure out where this is going wrong. Any more tips @adonno ?

adonno, 2020-11-24:
> OK, I deleted the node in ESPHome and compiled a new firmware. Flashed it to the D1, filled in wifi details via the captive portal and rebooted the whole thing. Same scenario as above. ESPHome shows no logs for the node except 'connected', ESPHome flasher shows everything as stated above when I open the node in HA. Tags are recognized by ESPHome Flasher when I present them but they trigger no automation. I can't for the life of me figure out where this is going wrong. Any more tips @adonno ?

Wait, hold on, the reader send the tag ID to HA?
I thought that was the issue ? Well then it's an issue with your automation please share your automation .

Closed 2020-11-23.

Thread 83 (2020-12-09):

Put PN532 Switches in Images + Schematic to I²C

mpmoeller, 2020-12-09:
Hey,

Possibly like many others, the _recent_ Home Assistant announcements brought me to your project. I literally just finished my first self-soldered tag reader 🥳 . Clearly lacking talent, the first device ended up in smoke, the second one had a buzzer for 2 seconds only before gravity decided that it will do well enough w/o it 🙈.

Disclosing that I am a total beginner I have a small feedback on documentation:

**_Please put the PN532 switches in your images + schematic to `I²C`._**

AFAICT, the pictures used in the [README.md](https://github.com/adonno/tagreader/blob/master/README.md) still have the switches put to `SPI`, see:

- https://github.com/adonno/tagreader/blob/master/docs/cases.jpg
- https://github.com/adonno/tagreader/blob/master/docs/open-case.jpg

In the schematic, the switches are set to `HSU`, see:

- https://github.com/adonno/tagreader/blob/master/Schematics/tag_reader_schematics_v2.png

Of course, I read that the switches have to be put to `I²C` and afterwards I learned that this was introduced with release 4.0. But being new in that game, things easily overwhelm and I was unsure if the positions were correct. So any (visual) guidance is helpful.

In my particular case, PN532 wasn't scanning because I simply inverted the setting. Luckily only 2 options exist, hence I was able to solve the "problem" myself. But for future beginners to come, you might want to spare them efforts and headaches.

Thanks,
Martin

waazdakka, 2021-01-07:
Hello mpmoeller!
What setting are you talking about, the switches ?
I followed the schematics (https://github.com/adonno/tagreader/blob/master/Schematics/tag_reader_schematics_v2.png) and not the photo of the finished case, but I never succeed to have neither the scanner working or the led on :(
I can't figure out what I've done wrong on here!
A little help ?
Thanks!!!

mpmoeller, 2021-01-07:
Hey @waazdakka,

In the schematics you see the big red PN532 board at the right.

On board you see a little black box w/ yellow switches and a „legend“ how to put them.

The schematics show them as 0/0 (HSU), but to make the PN532 run w/ I2C you need to put them to 1/0, i.e. change one switch.

Orherwise you won‘t hear any beeps or se any LED flashing as the PN532 won‘t „talk“ to the main processor.

The change to I2C only came recently. It is mentioned in the text, but I suspect that the pictures show the state „before“.

Best.

waazdakka, 2021-01-08:
Hey,

Thanks for your fast answer!

I followed the Readme instructions and your indications, but I don't have any success with my tagreader 😭
Major question : the schematic is completeley different than the open case photo!

While the schematics use SDA and SCL ports, the photo shows wires on MSO, MOSI and SS ports.
On the Wifi board, the D3 port is solder on the photo, while it's not in use on the schematic 🙄

I followed the schematic with no success, maybe I should follow the photo?

Thanks again!

mpmoeller, 2021-01-08:
I followed the schematic and surrounding text w/o any problems (except the switches)

Good luck!

Re4DeR, 2021-01-20:
thanks. after inverting switch setting, it works

adonno, 2021-05-01:
update the images

Closed 2021-05-01.

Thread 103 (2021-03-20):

Unable to Flash

seanmccabe, 2021-03-20:
Hi there,

I am totally new to this and done my best to Google and try and figure this out.

I have wired everything up, and plyggin power into the board via USB both the boards light up, but I am having issues flashing this.

In ESPHome home in Docker I've copied in the tagreader.yaml and compiled. Plug the board in by USB and can see USB Serial.

Attempt to then upload over USB and get the following:

```
INFO Successfully compiled program.
INFO Running:  esptool.py --before default_reset --after hard_reset --baud 460800 --chip esp8266 --port /dev/ttyUSB0 write_flash 0x0 /config/tagreader/.pioenvs/tagreader/firmware.bin
esptool.py v2.8
Serial port /dev/ttyUSB0
Connecting........_____....._____....._____....._____....._____....._____....._____

A fatal error occurred: Failed to connect to ESP8266: Timed out waiting for packet header
INFO Upload with baud rate 460800 failed. Trying again with baud rate 115200.
INFO Running:  esptool.py --before default_reset --after hard_reset --baud 115200 --chip esp8266 --port /dev/ttyUSB0 write_flash 0x0 /config/tagreader/.pioenvs/tagreader/firmware.bin
esptool.py v2.8
Serial port /dev/ttyUSB0
Connecting........_____....._____....._____....._____....._____....._____....._____

A fatal error occurred: Failed to connect to ESP8266: Timed out waiting for packet header
```

Really don't know what I am doing wrong here, and everything I Google just confuses me more, so looking for some plain english help.

Thanks!

zuidwijk, 2021-03-20:
Error message is easy: it can't connect.

Either a faulty esp, or there is something connected to the rx or tx, or the usb chip is faulty.

Either way... no connection between the esp and usb chip

seanmccabe, 2021-03-21:
Definately nothing in the rx or tx, completely untouched.
Will try flashing another unwired (didnt realise you could do this).

Thanks.

seanmccabe, 2021-03-21:
Ok, deffo faulty chip, or something else isnt quite right.
As just flashed an unsoldered unit without issue.

Maybe just to check Im doing this right (long time since I've done electronics).
The 5v line, is that one cable to the LED, and one to the PN532 yes? Both just soldered at the 5v terminal on the D1 mini.

zuidwijk, 2021-03-21:
Now I do remember that a faulty led could cause this too. In that case, unsolder the led. See if it works.

seanmccabe, 2021-03-28:
OK so second attempt at soldering, programmed beforehand, finished soldering and doesn't work.
Anyone see what I'm doing wrong, I'm not the best, but can't see any glaring issues...

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

seanmccabe, 2021-03-28:
> Now I do remember that a faulty led could cause this too. In that case, unsolder the led. See if it works.

Ok, turns out yes, it is the LED, am i soldering it wrong? Just to make sure before i return them as faulty.

Also, is there a way to solder it in the meantime without the LED?

seanmccabe, 2021-04-04:
Sorted

Closed 2021-04-04.

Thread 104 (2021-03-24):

No response from PN532 - rolling

a8ree, 2021-03-24:
I'm a noob to ESP and soldering isn't my forte but I think I did a decent job on soldering the pins to the NFC board. I've attached and before soldering to ESP and the buzzer, LED, I thought I would check it was functioning - but it's not.
[https://photos.app.goo.gl/GULpJfSDQdQMDoAq8](url)

It is successfully added to HA - and it shows online. No tags are being read, so I enabled debug
The LED power light on the NFC board is lit - I've got pin 1 set to 1 and 2 set to 0.

Any ideas whats going wrong>?

INFO Connecting to hall_frontdoor_nfc.local:6053 (192.168.1.64)
INFO Successfully connected to hall_frontdoor_nfc.local
[09:19:46][I][app:105]: ESPHome version 1.16.2 compiled on Mar 23 2021, 22:48:10
[09:19:46][C][wifi:443]: WiFi:
[09:19:46][C][wifi:303]:   SSID: [redacted]
[09:19:46][C][wifi:304]:   IP Address: 192.168.1.64
[09:19:46][C][wifi:306]:   BSSID: [redacted]
[09:19:46][C][wifi:307]:   Hostname: 'hall_frontdoor_nfc'
[09:19:46][C][wifi:311]:   Signal strength: -53 dB ▂▄▆█
[09:19:46][V][wifi:313]:   Priority: -2.0
[09:19:46][C][wifi:315]:   Channel: 6
[09:19:46][C][wifi:316]:   Subnet: 255.255.255.0
[09:19:46][C][wifi:317]:   Gateway: 192.168.1.1
[09:19:46][C][wifi:318]:   DNS1: 8.8.4.4
[09:19:46][C][wifi:319]:   DNS2: 8.8.8.8
[09:19:46][C][i2c:028]: I2C Bus:
[09:19:46][C][i2c:029]:   SDA Pin: GPIO4
[09:19:46][C][i2c:030]:   SCL Pin: GPIO5
[09:19:46][C][i2c:031]:   Frequency: 400000 Hz
[09:19:46][C][template.switch:058]: Template Switch 'hall_frontdoor_nfc Buzzer Enabled'
[09:19:46][C][template.switch:058]:   Icon: 'mdi:volume-high'
[09:19:46][C][template.switch:059]:   Restore State: YES
[09:19:46][C][template.switch:060]:   Optimistic: YES
[09:19:47][C][template.switch:058]: Template Switch 'hall_frontdoor_nfc LED enabled'
[09:19:47][C][template.switch:058]:   Icon: 'mdi:alarm-light-outline'
[09:19:47][C][template.switch:059]:   Restore State: YES
[09:19:47][C][template.switch:060]:   Optimistic: YES
[09:19:47][C][esp8266_pwm:022]: ESP8266 PWM:
[09:19:47][C][esp8266_pwm:023]:   Pin: GPIO13 (Mode: OUTPUT)
[09:19:47][C][esp8266_pwm:024]:   Frequency: 784.0 Hz
[09:19:47][C][fastled:019]: FastLED light:
[09:19:47][C][fastled:020]:   Num LEDs: 1
[09:19:47][C][fastled:021]:   Max refresh rate: 400
[09:19:47][C][logger:185]: Logger:
[09:19:47][C][logger:186]:   Level: VERBOSE
[09:19:47][C][logger:187]:   Log Baud Rate: 115200
[09:19:47][C][logger:188]:   Hardware UART: UART0
[09:19:47][C][light:178]: Light 'hall_frontdoor_nfc LED'
[09:19:47][C][light:180]:   Default Transition Length: 0.0s
[09:19:47][C][light:181]:   Gamma Correct: 2.80
[09:19:47][C][pn532:334]: PN532:
[09:19:47][C][pn532:346]:   Update Interval: 1.0s
[09:19:47][C][pn532_i2c:125]:   Address: 0x24
[09:19:47][D][rtttl:093]: Playback finished
[09:19:47][C][status:034]: Status Binary Sensor 'hall_frontdoor_nfc Status'
[09:19:47][C][status:034]:   Device Class: 'connectivity'
[09:19:47][C][rtttl:017]: Rtttl
[09:19:47][C][captive_portal:169]: Captive Portal:
[09:19:47][V][pn532:233]: Reading ACK...
[09:19:47][V][pn532:244]: ACK valid: YES
[09:19:47][V][pn532_i2c:040]: Reading response
[09:19:47][V][pn532_i2c:029]: Timed out waiting for readiness from PN532!
[09:19:47][V][pn532:255]: Turning RF field OFF
[09:19:47][V][pn532:233]: Reading ACK...
[09:19:47][V][pn532:244]: ACK valid: YES
[09:19:47][C][ota:029]: Over-The-Air Updates:
[09:19:47][C][ota:030]:   Address: hall_frontdoor_nfc.local:8266
[09:19:47][C][api:095]: API Server:
[09:19:47][C][api:096]:   Address: hall_frontdoor_nfc.local:6053
[09:19:48][V][pn532:233]: Reading ACK...
[09:19:48][V][pn532:244]: ACK valid: YES
[09:19:48][V][pn532_i2c:040]: Reading response
[09:19:48][V][pn532_i2c:029]: Timed out waiting for readiness from PN532!
[09:19:48][V][pn532:255]: Turning RF field OFF
[09:19:48][V][pn532:233]: Reading ACK...
[09:19:48][V][pn532:244]: ACK valid: YES
[09:19:49][V][pn532:233]: Reading ACK...
[09:19:49][V][pn532:244]: ACK valid: YES
[09:19:49][V][pn532_i2c:040]: Reading response
[09:19:49][V][pn532_i2c:029]: Timed out waiting for readiness from PN532!
[09:19:49][V][pn532:255]: Turning RF field OFF
[09:19:49][V][pn532:233]: Reading ACK...
[09:19:49][V][pn532:244]: ACK valid: YES
[09:19:50][V][pn532:233]: Reading ACK...
[09:19:50][V][pn532:244]: ACK valid: YES
[09:19:50][V][pn532_i2c:040]: Reading response
[09:19:50][V][pn532_i2c:029]: Timed out waiting for readiness from PN532!
[09:19:50][V][pn532:255]: Turning RF field OFF
[09:19:50][V][pn532:233]: Reading ACK...
[09:19:50][V][pn532:244]: ACK valid: YES
[09:19:51][V][pn532:233]: Reading ACK...
[09:19:51][V][pn532:244]: ACK valid: YES
[09:19:51][V][pn532_i2c:040]: Reading response
[09:19:51][V][pn532_i2c:029]: Timed out waiting for readiness from PN532!
[09:19:51][V][pn532:255]: Turning RF field OFF
[09:19:51][V][pn532:233]: Reading ACK...
[09:19:51][V][pn532:244]: ACK valid: YES
[09:19:52][V][pn532:233]: Reading ACK...
[09:19:52][V][pn532:244]: ACK valid: YES
[09:19:52][V][pn532_i2c:040]: Reading response
[09:19:52][V][pn532_i2c:029]: Timed out waiting for readiness from PN532!
[09:19:52][V][pn532:255]: Turning RF field OFF
[09:19:52][V][pn532:233]: Reading ACK...
[09:19:52][V][pn532:244]: ACK valid: YES
[09:19:53][V][pn532:233]: Reading ACK...
[09:19:53][V][pn532:244]: ACK valid: YES
[09:19:53][V][pn532_i2c:040]: Reading response
[09:19:53][V][pn532_i2c:029]: Timed out waiting for readiness from PN532!
[09:19:53][V][pn532:255]: Turning RF field OFF
[09:19:53][V][pn532:233]: Reading ACK...
[09:19:53][V][pn532:244]: ACK valid: YES
[09:19:54][V][pn532:233]: Reading ACK...
[09:19:54][V][pn532:244]: ACK valid: YES
[09:19:54][V][pn532_i2c:040]: Reading response
[09:19:54][V][pn532_i2c:029]: Timed out waiting for readiness from PN532!
[09:19:54][V][pn532:255]: Turning RF field OFF
[09:19:54][V][pn532:233]: Reading ACK...
[09:19:54][V][pn532:244]: ACK valid: YES
[09:19:55][V][pn532:233]: Reading ACK...
[09:19:55][V][pn532:244]: ACK valid: YES
[09:19:55][V][pn532_i2c:040]: Reading response
[09:19:55][V][pn532_i2c:029]: Timed out waiting for readiness from PN532!
[09:19:55][V][pn532:255]: Turning RF field OFF
[09:19:55][V][pn532:233]: Reading ACK...
[09:19:55][V][pn532:244]: ACK valid: YES
[09:19:56][V][pn532:233]: Reading ACK...
[09:19:56][V][pn532:244]: ACK valid: YES
[09:19:56][V][pn532_i2c:040]: Reading response
[09:19:56][V][pn532_i2c:029]: Timed out waiting for readiness from PN532!
[09:19:56][V][pn532:255]: Turning RF field OFF
[09:19:56][V][pn532:233]: Reading ACK...
[09:19:56][V][pn532:244]: ACK valid: YES

a8ree, 2021-03-24:
Sorry, it was a bad solder

Closed 2021-03-24.

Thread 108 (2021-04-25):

Flash fails with: Resolving IP address of tagreader.local

bsrdjan, 2021-04-25:
Hi,

just assembled the tag-reader and connected via usb to laptop running HA. The flash fails with

`Program failed with code 1`

The red LED on NFC module is on and a quiet permanent tone can be heard from buzzer.

Status:

ESPHome: Materializev1.16.2 D
HA: core-2021.4.6

Log
```
INFO Reading configuration /config/esphome/tagreader.yaml...
INFO Generating C++ source...
INFO Compiling app...
INFO Running:  platformio run -d /config/esphome/tagreader
Processing tagreader (board: d1_mini; framework: arduino; platform: espressif8266@2.6.2)
--------------------------------------------------------------------------------
HARDWARE: ESP8266 80MHz, 80KB RAM, 4MB Flash
PACKAGES:
 - framework-arduinoespressif8266 3.20704.0 (2.7.4)
 - tool-esptool 1.413.0 (4.13)
 - tool-esptoolpy 1.20800.0 (2.8.0)
 - toolchain-xtensa 2.40802.200502 (4.8.2)
Library Manager: Installing Update
Library Manager: Already installed, built-in library
Dependency Graph
|-- <ESPAsyncTCP-esphome> 1.2.3
|   |-- <ESP8266WiFi> 1.0
|-- <ESP8266WiFi> 1.0
|-- <ESP8266mDNS> 1.2
|   |-- <ESP8266WiFi> 1.0
|-- <ESPAsyncWebServer-esphome> 1.2.7
|   |-- <ESPAsyncTCP-esphome> 1.2.3
|   |   |-- <ESP8266WiFi> 1.0
|   |-- <Hash> 1.0
|   |-- <ESP8266WiFi> 1.0
|-- <Wire> 1.0
|-- <FastLED> 3.3.2
|   |-- <SPI> 1.0
|   |-- <EspSoftwareSerial> 6.8.5
|-- <DNSServer> 1.1.1
|   |-- <ESP8266WiFi> 1.0
Compiling /data/tagreader/.pioenvs/tagreader/src/main.cpp.o
Linking /data/tagreader/.pioenvs/tagreader/firmware.elf
Retrieving maximum program size /data/tagreader/.pioenvs/tagreader/firmware.elf
Building /data/tagreader/.pioenvs/tagreader/firmware.bin
Checking size /data/tagreader/.pioenvs/tagreader/firmware.elf
RAM:   [=====     ]  48.8% (used 39976 bytes from 81920 bytes)
Flash: [=====     ]  45.7% (used 477776 bytes from 1044464 bytes)
Creating BIN file "/data/tagreader/.pioenvs/tagreader/firmware.bin" using "/root/.platformio/packages/framework-arduinoespressif8266/bootloaders/eboot/eboot.elf" and "/data/tagreader/.pioenvs/tagreader/firmware.elf"
========================= [SUCCESS] Took 11.59 seconds =========================
INFO Successfully compiled program.
INFO Resolving IP address of tagreader.local
ERROR Error resolving IP address of tagreader.local. Is it connected to WiFi?
ERROR (If this error persists, please set a static IP address: https://esphome.io/components/wifi.html#manual-ips)
ERROR Error resolving IP address: Error resolving address with mDNS: Did not respond. Maybe the device is offline., [Errno -5] No address associated with hostname
```

Any ideas what goes wrong?

adonno, 2021-04-25:
No need to flash it they came pre-flashed already

if you want to flash an device the first time you will need to use esphome-flasher and connect the esp to your pc
esphome-flasher can also be used to check the logs

https://github.com/esphome/esphome-flasher/releases/tag/v1.3.0

bsrdjan, 2021-04-26:
Thanks adonno. Tried with 1.3.0 and got following log:

```shell
Using '/dev/cu.usbserial-144440' as serial port.
Connecting........_____....._____....._____....._____....._____....._____....._____
Unexpected error: ESP Chip Auto-Detection failed: Failed to connect to Espressif device:
Timed out waiting for packet header
```
Flashing another D1-mini w/o NFC module works fine. Does wiring looks correct?

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

adonno, 2021-05-01:
Seems to be a soldering issue there must be a short somewhere. Unfortunately, I can't troubleshoot and from what I see from the images, they look fine. But can be finicky sometimes.  Maybe try **carefully** desoldering the PN532.

⚠️ The PN532 has very fragile connectors

bsrdjan, 2021-05-03:
> ⚠️ The PN532 has very fragile connectors

Thanks @adonno, re-soldering fixed the issue. Tags are detected only the buzzer and LED are not reacting when the tag is read. On power-up, the buzzer beeps and the LED flashes.

The buzzer works from dev tools but no sound (and no LED) on tag reading. Tag shows up in home assistant
```yaml
service: esphome.tagreader1_play_rtttl
data:
  song_str: >-
    beep:d=16,o=5,b=100:b
```

adonno, 2021-05-13:
The need to be enabled within HA when adding tag reader you got 4 new entities

Closed 2021-05-13.

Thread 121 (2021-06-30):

Cannot read nfc cards.

willemdej, 2021-06-30:
I have programmed an nfc card, when I hold the nfc card above the tag reader. there will be no automation activated.
I have set the debugging. very verbose this is my log;

INFO Reading configuration /config/esphome/tagreader.yaml...
INFO Starting log output from 192.168 using esphome API
INFO Connecting to 192.168:6053 (192.168.)
INFO Successfully connected to 192.168
[17:39:16][I][app:105]: ESPHome version 1.19.4 compiled on Jun 26 2021, 19:50:31
[17:39:16][C][wifi:484]: WiFi:
[17:39:16][C][wifi:344]:   SSID: [redacted]
[17:39:16][C][wifi:345]:   IP Address:
[17:39:16][C][wifi:347]:   BSSID: [redacted]
[17:39:16][C][wifi:348]:   Hostname: 'tagreader'
[17:39:16][C][wifi:352]:   Signal strength: -46 dB ▂▄▆█
[17:39:16][V][wifi:354]:   Priority: 0.0
[17:39:16][C][wifi:356]:   Channel: 6
[17:39:16][C][wifi:357]:   Subnet:
[17:39:16][C][wifi:358]:   Gateway:
[17:39:16][C][wifi:359]:   DNS1:
[17:39:16][C][wifi:360]:   DNS2: (IP unset)
[17:39:16][C][i2c:028]: I2C Bus:
[17:39:16][C][i2c:029]:   SDA Pin: GPIO4
[17:39:16][C][i2c:030]:   SCL Pin: GPIO5
[17:39:16][C][i2c:031]:   Frequency: 400000 Hz
[17:39:16][C][template.switch:058]: Template Switch 'TagReader Buzzer Enabled'
[17:39:16][C][template.switch:058]:   Icon: 'mdi:volume-high'
[17:39:16][C][template.switch:059]:   Restore State: YES
[17:39:16][C][template.switch:060]:   Optimistic: YES
[17:39:16][C][template.switch:058]: Template Switch 'TagReader LED enabled'
[17:39:16][C][template.switch:058]:   Icon: 'mdi:alarm-light-outline'
[17:39:16][C][template.switch:059]:   Restore State: YES
[17:39:16][C][template.switch:060]:   Optimistic: YES
[17:39:16][C][esp8266_pwm:022]: ESP8266 PWM:
[17:39:16][C][esp8266_pwm:023]:   Pin: GPIO13 (Mode: OUTPUT)
[17:39:16][C][esp8266_pwm:024]:   Frequency: 988.0 Hz
[17:39:16][C][fastled:019]: FastLED light:
[17:39:16][C][fastled:020]:   Num LEDs: 1
[17:39:16][C][fastled:021]:   Max refresh rate: 400
[17:39:16][C][logger:189]: Logger:
[17:39:16][C][logger:190]:   Level: VERY_VERBOSE
[17:39:16][C][logger:191]:   Log Baud Rate: 115200
[17:39:16][C][logger:192]:   Hardware UART: UART0
[17:39:16][C][light:188]: Light 'TagReader LED'
[17:39:16][C][light:190]:   Default Transition Length: 0.0s
[17:39:16][C][light:191]:   Gamma Correct: 2.80
[17:39:16][C][pn532:344]: PN532:
[17:39:16][C][pn532:356]:   Update Interval: 1.0s
[17:39:16][C][pn532_i2c:125]:   Address: 0x24
[17:39:16][C][status:034]: Status Binary Sensor 'TagReader Status'
[17:39:16][C][status:034]:   Device Class: 'connectivity'
[17:39:16][C][rtttl:017]: Rtttl
[17:39:16][C][captive_portal:148]: Captive Portal:
[17:39:16][C][ota:029]: Over-The-Air Updates:
[17:39:16][C][ota:030]:   Address: 192.168.8266
[17:39:16][C][api:095]: API Server:
[17:39:16][C][api:096]:   Address: 192.168.:6053
[17:39:17][VV][scheduler:152]: Running interval '' with interval=5000 last_execution=5882826 (now=5887830)
[17:39:17][VV][light.addressable:168]: Addressable Light 'TagReader LED' (effect_active=NO next_show=NO)
[17:39:17][VV][light.addressable:172]:   [ 0] Color: R=  0 G=  0 B=  0 W=  0
[17:39:17][VV][light.addressable:174]:
[17:39:21][VV][api.service:220]: on_ping_request: PingRequest {}
[17:39:21][VV][api.service:032]: send_ping_response: PingResponse {}
[17:39:22][VV][scheduler:152]: Running interval '' with interval=5000 last_execution=5887826 (now=5892828)
[17:39:22][VV][light.addressable:168]: Addressable Light 'TagReader LED' (effect_active=NO next_show=NO)
[17:39:22][VV][light.addressable:172]:   [ 0] Color: R=  0 G=  0 B=  0 W=  0
[17:39:22][VV][light.addressable:174]:

adonno, 2021-07-16:
Is that a purchased tag reader or one you assembled?  I would suggest connecting you reader to your PC via USB and using ESPHome Flasher to read into the logs, If there is any issue with the PN532 chip it will only show on the boot

adonno, 2021-09-17:
no reply  for 60 days , issue closed

Closed 2021-09-17.

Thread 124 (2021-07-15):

Received 2 new card readers but 1st one is not working...

danielbrunt57, 2021-07-15:
I received my two tag readers yesterday, thank you.  The first one I was able to connect to its wi-fi URL and configured it to connect to my wi-fi and it showed up in HA but it will not scan any tags.  I moved onto the 2nd one and immediately noticed a difference between the two... the first one has no indicator lights after power up whereas the 2nd one lit up with a red LED.  The 1st one is successfully connected to my wi-fi as I can ping its DHCP address but nothing beyond that.  It does emit a sound shortly after being powered up but no red LED and no scans.  I can turn on the blue LED from HA and have noticed the blue LED is somewhat different than the 2nd reader... the first looks like four dots in a circle but the 2nd reader looks like a single bright blue LED.

danielbrunt57, 2021-07-15:
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

danielbrunt57, 2021-07-16:
Fixed!

Opened the case and found a bad solder joint on the ground...
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

Also found the reason for the difference in the blue LED's...
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

adonno, 2021-07-16:
Hey, @danielbrunt57 I am sorry for the poorly soldered GND I usually test them all and take great care in making sure I don't send defective devices.

I also seem to have sent you TWO Different versions of the LID which is also not standard practice.
Is there anything I can do?

danielbrunt57, 2021-07-16:
You can send me a new lid so they are the same.  I carefully dremelled the white plastic away on the 4 dot version so I see a blue circle from inside it now but it still appears as 4 dots which I can see from the back side if I hold it up to a light.

While I got the first one up and running after re-soldering the GND, the green LED is not working.  Blue is working and if I turn that on and then scan, it just turns off rather than changing to green like my 2nd reader does.  Could that be another bad solder joint?

nielsrune, 2021-07-21:
Just to add to this, my LED isn't working at all.
After seeing this post, I opened the lid which has the hole (equal to the bottom one in OP's picture)

But the LED won't turn on, even when switching on in HA :-(

adonno, 2021-08-10:
@danielbrunt57   @nielsrune  would you mind hitting me up with an email please ?  so that I don't lose track?

nielsrune, 2021-08-10:
> @danielbrunt57 @nielsrune would you mind hitting me up with an email please ? so that I don't lose track?

@adonno I beat you to it :-) See my e-mail of August 8th to adonno@adonno.com, subject "LED seems to be faulty or missing"

adonno, 2021-08-11:
i'm working on a solution by end of the week

0n3-70uch, 2021-08-19:
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

Hello, I have the same problem. The LED worked fine for just one hour...

hermanops, 2021-08-23:
Hi, I also have this problem. I bought the Tag Reader Sandwich Version and the LED isn't working anymore

Strangehadron, 2021-08-24:
I've made a tag reader, same wiring than the schematics and same code and the led wasn't working either. (a W2812B)

I've comment the line : `default_transition_length: 10ms `to desactivate it and now i can turn on/off and change the color of my led via HA, but the led don't flash when scan a tag.

Using the last version of esphome : 2021.8

nielsrune, 2021-09-01:
> i'm working on a solution by end of the week

@adonno, any update on this one?
As per the picture I sent by e-mail, my LED seems physically missing.

adonno, 2021-09-16:
small update , i have been waiting on parts and they finally arrived i'll update you this weekend

0n3-70uch, 2021-09-16:
> small update , i have been waiting on parts and they finally arrived i'll update you this weekend

Great thank you.

adonno, 2021-09-28:
@danielbrunt57 i am unable to get back to you via email it seems i'm blocked ?

adonno, 2022-01-25:
everyone should have gotten their fixed devices?

danielbrunt57, 2022-01-25:
No sign of mine yet...

adonno, 2022-01-30:
yeah just noticed it's still in transit.  it was sent on Dec 8.
i will have to check with postal services there are several packages stuck

adonno, 2022-04-11:
this time they finally arrived. :-D

Closed 2022-04-11.

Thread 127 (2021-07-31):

3D printing questions

sharebear, 2021-07-31:
Hi!

I decided to try and make a couple of these with locally sourced parts and used it as an excuse to finally invest in a 3D printer ;)

My first issue is due to the fact that I have the Lolin V3.1.0 board, the USB and the switch aren't in the same place meaning that, no matter what I try the USB port doen't match up to the hole. Anyone else stumbled across this (I see in the issues others have used the Lolin board)? Any tips for a fix?

Next when researching the issue I found the V4.1 STL files on Thingverse that appear updated compared to the files in this repository. Trying this I have the same problem with the misaligned USB and there doesn't appear to be enough supports for the two boards. Am I right in guessing that this is to be used with the PCB here https://shop.adonno.com/products/tag-reader-pcb ?

What's the best solution in my situation? Should I just design my own case? Are there any source files to start from?

Perhaps add a note in the readme here regarding the relationship between the STLs in this repo and the V4.1 files on Thingverse?

adonno, 2021-08-10:
Hi

Yes the design wasn't made for a V3 board and thus won't fit into the case for now I haven't had the time to change the design to accept a v3 as of yet I might work on it in the coming weeks though

About the V4.1 case, that's also exact it's made for the PCB version and thus isn't on Github.
I am not keen on publicly sharing the source files, because it's a mess you might hit me up on discord if you want to try to change something

sharebear, 2021-08-10:
I brute forced the installation for now. I just clipped away a little plastic that was blocking the USB port and I'm not so bothered about the reset button not being accessible (easier to pop open the lid if the need arises, than finding something to stick through the hole).

Thanks for the project, it's been working nicely so far, the main weakness appears to be my soldering skills (second one I constructed appears to be fully working).

adonno, 2021-09-17:
glad to know everything worked out .

Closed 2021-09-17.

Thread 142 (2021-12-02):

Doesn't work with either of my esp32 devices

colemickens, 2021-12-02:
I have a nodemcu esp-32s and a devkit esp32 and both don't work.

The thing is, I used to have a esp32 that did work with the pn532 and I think it was one of these devices. I'm not sure if I upgraded esphome and it broke, or if something bad happened to this board?

```
[14:47:33][I][i2c.arduino:156]: Performing I2C bus recovery
[14:47:33][C][pn532:018]: Setting up PN532...
[14:47:33][D][pn532:033]: Found chip PN532
[14:47:33][D][pn532:034]: Firmware ver. 1.6
[14:47:33][E][esp32-hal-i2c.c:1434] i2cCheckLineState(): Bus Invalid State, TwoWire() Can't init sda=1, scl=0
[14:47:33][E][esp32-hal-i2c.c:1434] i2cCheckLineState(): Bus Invalid State, TwoWire() Can't init sda=1, scl=0
[14:47:33][E][component:112]: Component pn532 was marked as failed.
```

sometimes the version IS able to be retrieved, but often not.

colemickens, 2021-12-02:
```
[14:57:05][I][app:029]: Running through setup()...
[14:57:05][I][i2c.arduino:156]: Performing I2C bus recovery
[14:57:05][E][i2c.arduino:172]: Recovery failed: SCL is held LOW on the I2C bus
[14:57:05][E][esp32-hal-i2c.c:1434] i2cCheckLineState(): Bus Invalid State, TwoWire() Can't init sda=1, scl=0
[14:57:05][C][pn532:018]: Setting up PN532...
[14:57:05][E][pn532:022]: Error sending version command
[14:57:05][E][component:112]: Component pn532 was marked as failed.
```

some things I'm seeing online say that additional components are needed? Is the circuitry still the same if I don't have the speaker wired in?

adonno, 2021-12-23:
this is weird , can you send me a picture of your setup, please?

adonno, 2022-01-25:
closed due to no feedback

Closed 2022-01-25.

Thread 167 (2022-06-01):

Can´t read NFC tags

nedflanders11, 2022-06-01:
Hello!

Thanks for this wonderful project.

I´ve have received my tagreader this week. It worked fine the first day (integrated in my Home Assistent, reading tags, automations, ...). It was perfect.

In the evening I have unplugged the USB-C. On the next day I have plugged in the USB-C again. After a few seconds the tagreader was in status "connected" (Home Assistant).

From now on the tagreader didn´t read tags anymore. It´s still possible to switch on/off the LED, restarting, ..., but reading tags is not possible.

In the esphome-flasher is no log after scanning. But there are log entries when I switch on/off the LED, ...

Any suggestions? Thanks!

adonno, 2022-06-01:
Can you update your tagreader via[https://adonno.github.io/tagreader]() and let me know?

nedflanders11, 2022-06-01:
Thanks for your fast feedback.

Recommended update (ESPHome 2022.3.2) successfully done.
Unfortunately still the same behavior.
I have deleted the ESPHome integration in Home Assistant. Afterwards integrated again. Same behavior.

nedflanders11, 2022-06-01:
I´ve done a restart and have seen the following three errors:

I][logger:214]: Log initialized
[C][ota:461]: There have been 0 suspected unsuccessful boot attempts.
[I][app:029]: Running through setup()...
[I][i2c.arduino:161]: Performing I2C bus recovery
**[E][i2c.arduino:177]: Recovery failed: SCL is held LOW on the I2C bus**
[D][template.switch:050]:   Restored state ON
[D][switch:013]: 'TagReader Buzzer Enabled' Turning ON.
[D][switch:037]: 'TagReader Buzzer Enabled': Sending state ON
[D][template.switch:050]:   Restored state ON
[D][switch:013]: 'TagReader LED enabled' Turning ON.
[D][switch:037]: 'TagReader LED enabled': Sending state ON
[C][esp8266_pwm:017]: Setting up ESP8266 PWM Output...
[C][light:036]: Setting up light 'TagReader LED'...
[D][light:035]: 'TagReader LED' Setting:
[D][light:040]:   Color mode: RGB
[D][light:084]:   Transition length: 1.0s
[C][pn532:018]: Setting up PN532...
**[E][pn532:022]: Error sending version command
[E][component:112]: Component pn532 was marked as failed.**

adonno, 2022-06-02:
Would you mind opening the device and sending me an image of the soldering spots please ?

nedflanders11, 2022-06-03:
Please see attachment:
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

nedflanders11, 2022-06-03:
Please see attachment:
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

adonno, 2022-06-03:
I'll send you a new one i guess ,
Can you email me your initial order number  adonno@adonno.com

adonno, 2022-06-05:
Ok i will come back to it by end of week

adonno, 2022-11-01:
sent a new device

Closed 2022-11-01.

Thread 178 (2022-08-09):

Suddenly unable to read cards

RichardMawdsley, 2022-08-09:
Hi, I built my own scanner from your details a few months back and it's been working great!

However it's suddenly just stopped reading tags.  Still connects fine in ESPHome/Home Assistant, all actions in the HA Device such as the LED/Restart function and from what I can tell the log (below) looks fine, but it just won't scan tags.  I've checked there is voltage going to the NFC board and it seems fine.

I've hit the install button in ESPHome/HA on the device a few times to reinstall it - once it did start reading them again until the device was restarted and it's never done it since.

[logs_tagreader-dad851_upload.txt](https://github.com/adonno/tagreader/files/9288942/logs_tagreader-dad851_upload.txt)

Any thoughts? Thanks.

RichardMawdsley, 2022-08-09:
Update:  I deleted the device from ESPHome and rediscovered/adopted it.  Instantly it was able to read tags again.  Restarting it via the Restart button on the device in Home Assistant multiple times and it successfully comes back up and I could read tags.  However, I then killed the power to it, waited a few seconds and switched it back on, and whilst it came back up and connected I'm now unable to read tags regardless of what I do.

So, this gives me hope that it's not hardware related but something config wise with the soft / hard reboot.  Has something changed? This is how i've been using it for months.

RichardMawdsley, 2022-08-09:
Further update..  Attempted to plug into computer to grab more detailed logs of the boot and have discovered an oddity that I assume is suggesting a failed boot.

Upon trying to connect, I get four separate possible outcomes following plugging it in:

1) No device found - Tags do not scan - The device itself makes the beep noise to suggest it's started and it shows as online in Home Assistant, but No device found to physically connect.

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

2) Device found, won't connect and hangs browser - Tags do not scan
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

3) It works - only happened once - It booted fine, I could connect and cards scanned fine.  Whilst my stupid arse didnt export the logs, I clearly saw the line with wording to effect of "Found hardware pn532".

4) pn532 error - If I'm very very quick after plugging it in, then before getting into state 2 above I can connect.  I miss some of the verbose log because i'm not there from the start.  It does not scan cards.  However, If I then hit the 'Reset Device' button I get a very clear:

[C][pn532:018]: Setting up PN532...
[E][pn532:022]: Error sending version command
[E][component:112]: Component pn532 was marked as failed.

It restarts and predictably no card scans.

So, clearly the pn532 is failing to start.  I've reattempted my previous comment of deleting and re-adopting but that seems to have given up too.  Only notable change I can see in the log is:  [11:08:54][C][i2c.arduino:047]:   Recovery: failed, SCL is held low on the bus.  Off to google that.

RichardMawdsley, 2022-08-13:
Unable to resolve, I ended up buying a new PN532 and replacing it.  Seems fine now.  Very odd that it would just give up but in this case it seems to have been faulty hardware.

Closed 2022-08-13.

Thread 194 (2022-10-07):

Not able to write Music Tag

gbfromhb, 2022-10-07:
I'm able to read a card just fine. It writes the tag ID and creats a tag in Home Assistant. I have created an Automation using this, and I'm able to play a Spotify Album to a Google Cast device.

What I'm having issues with is writing a music tag.

I first use the "Clean Tag" button. Your tag reader beeps, and the LED turns yellow.

I wave the card over the reader/writer, it beeps and the yellow light goes off.

I then call the "ESPHome: family_room_tag_reader_write_music_tag" service with the following.
music_url:
   spotify:album:7vEJAtP3KgKSpOHVgwm3Eh?si=N6nfodcgS-WqSOzWF1b_eA7vEJAtP3KgKSpOHVgwm3Eh

music_info: Beatles - 1

The tag reader beeps and the LED turns red.

I wave the card over the reader/writer, it beeps and the red light goes out.

I read the card, and this is what is being read from the card

event_type: tag_scanned
data:
  tag_id: 04-72-90-BA-AD-6C-81
  device_id: ad572ebe52e0a4eccf7726abadeeb8ca
origin: LOCAL
time_fired: "2022-10-07T22:41:56.383861+00:00"
context:
  id: 01GET9SH4ZNN8TDYH4FXV3HQQ8
  parent_id: null
  user_id: null

Any suggestion on what I may be doing wrong.

hannemann, 2022-10-08:
I am also playing around with this atm.
You have to prefix your URL with `https://open.spotify.com/` and listen to the event `esphome.music_tag`. You can find valid prefixes in the yaml. Search for `open.spotify` and you will see...

I also added my own URL prefix lms:// since i want to send the data being read to my Logitech Media Server.

gbfromhb, 2022-10-08:
I'm using the latest yaml file, and I don't seem to have the esphome.music_tag event avaliable either. I have recompile and had Home Assistant reinstall the tagreader device and the event does not seem to be there.

I have also installed the blueprint and the tagreader does not appear as a choice. I'm not sure where to go with this one.

hannemann, 2022-10-09:
Did you rewrite the URL? It should look like `https://open.spotify.com/album/7vEJAtP3KgKSpOHVgwm3Eh?si=N6nfodcgS-`. If not the `esphome.music_tag` event is not fired but `tag_scanned` instead.

One of the prefixes
- https://open.spotify.com
- https://music.apple.com
- sonos-2://
is mandatory for the `esphome.music_tag` event to be fired.

AFAIK the event becomes visible in HA as soon as you use it in an automation or used it at least once... not sure.
Try to listen to the event anyway. It should work even if it does not show up in the list.

I have ordered cards that are rectangular and slightly wider (45mm x 24mm) than the reader module (the red pcb) and smaller round ones that have 20mm in diameter. The rectangular ones work much better. Even through the 2.5 cm wooden tabletop! (the reader is screwed to the underside of the table facing down)

The round ones work reliably most of the time if i place them on the edge of the reader module instead of the center. I think that's related to the antennae which i think is the white rectangle on pcb but i could be wrong about that. If i place them in the center of the scan area than i mostly get the same results like you mentioned. Maybe they don't get enough energy or there is an interference or...

With both types of cards it works best if i hold them still a centimeter or two above the scan area for a few seconds. Try it and observe the esphome log of your reader.
You should see something like:
```
[02:44:08][D][pn532:162]: Found new tag '04-86-BA-06-19-6C-80'
[02:44:08][D][pn532:166]:   NDEF formatted records:
[02:44:08][D][pn532:168]:     U - lms://Radio Stationen/0
[02:44:08][D][pn532:168]:     T - Radio Paradise
[02:44:08][D][pn532:295]: Waiting to read next tag
```
The U - should be `https://open.spotify.com/album/7vEJAtP3KgKSpOHVgwm3Eh?si=N6nfodcgS-` in your case.
If you see something like:
```
[02:46:32][D][pn532:162]: Found new tag '04-34-29-6C-39-61-80'
[02:46:32][D][pn532:295]: Waiting to read next tag
```
the reading failed but the `tag_scanned` event is fired anyway with the uid of the tag instead of an `esphome.music_tag` event.

Hope that helps a bit.

gbfromhb, 2022-10-10:
I think I have it working, but the problem I'm having is that I'm pretty sure for me to get Spot Cast to work with my configuration is to use the "spotify:" not the "https://open.spotify.com/". Is there anyway you can also trigger the esphome.music_tag with this prefix as well?

hannemann, 2022-10-11:
It's possible but you have to alter the code...

Why not transform it in your automation?

If your url would look like `https://open.spotify.com/album/7vEJAtP3KgKSpOHVgwm3Eh?si=N6nfodcgS-` you could transform it with Jinja within HA like so (Developer Tools -> Template):
```
{% set parts = "https://open.spotify.com/album/7vEJAtP3KgKSpOHVgwm3Eh?si=N6nfodcgS-".replace('https://open.spotify.com/', '').split('/') %}
{{ ['spotify', parts[0], parts[1]] | join(':') }}
```
I don't have a clue how spot cast works but within an automation you could use the trigger data:
```
service: media_player.play_media
target:
  entity_id: media_player.the_player
data:
  media_content_type: music
  media_content_id: >
    {% set parts = trigger.event.data.url.replace('https://open.spotify.com/', '').split('/') %}
    {{ ['spotify', parts[0], parts[1]] | join(':') }}
```
Something like that.

gbfromhb, 2022-10-11:
That was the direction I was heading, and thank you for the code. The prefix I'm using has to do with Home Assistant (I'm pretty sure). This seems to be the only way I'm able to play Spotify via a service or automation.

gbfromhb, 2022-10-11:
First of all thank you for everthing and your already assembled tag reader the best. I ended up modifiing your yaml file and changed this part. I added the spotify_2 variable and delt with it in the conditionals. Here is the section I modified.

`    - lambda: |-
        id(source)="";
        id(url)="";
        id(info)="";
        if (tag.has_ndef_message()) {
          auto message = tag.get_ndef_message();
          auto records = message->get_records();
          for (auto &record : records) {
            std::string payload = record->get_payload();
            std::string type = record->get_type();
            size_t hass = payload.find("https://www.home-assistant.io/tag/");
            size_t applemusic = payload.find("https://music.apple.com");
            size_t spotify = payload.find("https://open.spotify.com");
            size_t spotify_2 = payload.find("spotify:");
            size_t sonos = payload.find("sonos-2://");

            if (type == "U" and hass != std::string::npos ) {
              ESP_LOGD("tagreader", "Found Home Assistant tag NDEF");
              id(source)="hass";
              id(url)=payload;
              id(info)=payload.substr(hass + 34);
            }
            else if (type == "U" and applemusic != std::string::npos ) {
              ESP_LOGD("tagreader", "Found Apple Music tag NDEF");
              id(source)="amusic";
              id(url)=payload;
            }
            else if (type == "U" and spotify != std::string::npos ) {
              ESP_LOGD("tagreader", "Found Spotify tag NDEF");
              id(source)="spotify";
              id(url)=payload;
            }
            else if (type == "U" and spotify_2 != std::string::npos ) {
              ESP_LOGD("tagreader", "Found Spotify tag NDEF");
              id(source)="spotify";
              id(url)=payload;
            }
            else if (type == "U" and sonos != std::string::npos ) {
              ESP_LOGD("tagreader", "Found Sonos app tag NDEF");
              id(source)="sonos";
              id(url)=payload;
            }
            else if (type == "T" ) {
              ESP_LOGD("tagreader", "Found music info tag NDEF");
              id(info)=payload;
            }
            else if ( id(source)=="" ) {
              id(source)="uid";
            }
          }
        }
        else {
          id(source)="uid";
        }
`

hannemann, 2022-10-12:
I'm not the author of the code nor did i develop the tagreader hardware ;) I stumpled upon your issue because i had a similar problem ;)

I would not recommend to modify the tagreader code since you have to reapply your changes in case of an update. If you could do it in HA that's the preferred way, easier and more flexible.

If you need that string: `spotify:album:7vEJAtP3KgKSpOHVgwm3Eh?si=N6nfodcgS-` program your tag with the url `https://open.spotify.com/spotify:album:7vEJAtP3KgKSpOHVgwm3Eh?si=N6nfodcgS-` and use it in HA like so:
```
"{{ trigger.event.data.url.replace('https://open.spotify.com/', '') }}"
```

adonno, 2022-11-01:
this will wrok fine, even when reflashing or updating the tagreader @gbfromhb 's modification should remain untouched.

The tagreader.yaml is a community effort :-D not only mine
the PCB is also a community effort :-D

Closed 2022-11-01.

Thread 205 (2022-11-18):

Can't make it work ...

Elmout33, 2022-11-18:
Hi, I follow all steps describe but nothing works ...

I have HA on a Raspberry pi 4 so I can't install from it to the D1 Mini so I try to do so from my computer. It seems ok according to the log in the windows console :
`INFO Reading configuration C:\Users\lerou\Desktop\tagreader-1.yaml...
INFO Generating C++ source...
INFO Compiling app...
Processing tagreader (board: d1_mini; framework: arduino; platform: platformio/espressif8266 @ 3.2.0)
------------------------------------------------------------------------------------------------------------------------Verbose mode can be enabled via `-v, --verbose` option
CONFIGURATION: https://docs.platformio.org/page/boards/espressif8266/d1_mini.html
PLATFORM: Espressif 8266 (3.2.0) > WeMos D1 R2 and mini
HARDWARE: ESP8266 80MHz, 80KB RAM, 4MB Flash
PACKAGES:
 - framework-arduinoespressif8266 @ 3.30002.0 (3.0.2)
 - tool-esptool @ 1.413.0 (4.13)
 - toolchain-xtensa @ 2.100300.210717 (10.3.0)
LDF: Library Dependency Finder -> https://bit.ly/configure-pio-ldf
LDF Modes: Finder ~ off, Compatibility ~ soft
Found 39 compatible libraries
Scanning dependencies...
Dependency Graph
|-- ESPAsyncTCP-esphome @ 1.2.3
|-- ESPAsyncWebServer-esphome @ 2.1.0
|   |-- ESPAsyncTCP-esphome @ 1.2.3
|   |-- Hash @ 1.0
|   |-- ESP8266WiFi @ 1.0
|-- DNSServer @ 1.1.1
|-- ESP8266WiFi @ 1.0
|-- ESP8266mDNS @ 1.2
|-- Wire @ 1.0
|-- Improv @ 1.2.3
|-- NeoPixelBus @ 2.6.9
|   |-- SPI @ 1.0
Building in release mode
Compiling .pioenvs\tagreader\src\main.cpp.o
Linking .pioenvs\tagreader\firmware.elf
Retrieving maximum program size .pioenvs\tagreader\firmware.elf
Checking size .pioenvs\tagreader\firmware.elf
Advanced Memory Usage is available via "PlatformIO Home > Project Inspect"
RAM:   [====      ]  43.5% (used 35600 bytes from 81920 bytes)
Flash: [=====     ]  48.7% (used 508749 bytes from 1044464 bytes)
Building .pioenvs\tagreader\firmware.bin
Creating BIN file ".pioenvs\tagreader\firmware.bin" using "C:\Users\lerou\.platformio\packages\framework-arduinoespressif8266\bootloaders\eboot\eboot.elf" and ".pioenvs\tagreader\firmware.elf"
esp8266_copy_factory_bin([".pioenvs\tagreader\firmware.bin"], [".pioenvs\tagreader\firmware.elf"])
============================================= [SUCCESS] Took 13.68 seconds =============================================INFO Successfully compiled program.
Found multiple options, please choose one:
  [1] COM3 (USB-SERIAL CH340 (COM3))
  [2] Over The Air (tagreader.local)
(number): 1
esptool.py v3.3.1
Serial port COM3
Connecting....
Chip is ESP8266EX
Features: WiFi
Crystal is 26MHz
MAC: c8:c9:a3:0a:cd:f7
Uploading stub...
Running stub...
Stub running...
Changing baud rate to 460800
Changed.
Configuring flash size...
Auto-detected Flash size: 4MB
Flash will be erased from 0x00000000 to 0x0007dfff...
Compressed 512896 bytes to 348106...
Wrote 512896 bytes (348106 compressed) at 0x00000000 in 8.5 seconds (effective 482.4 kbit/s)...
Hash of data verified.

Leaving...
Hard resetting via RTS pin...
INFO Successfully uploaded program.
INFO Starting log output from COM3 with baud rate 115200
[20:58:05]rll\x90r☻$↕\xe2n

\xc4
l\xc7
b|\x8e\x90☻↕\x92r↕b\xc4
b♦\xf2nn☻lnn↕b
b∟p\x8c$blrlp\xf2n►☻

\x90
l
\x8c☻

b
n\xe2n\xc7
\xc4♦
b\xc4\xf2nn'l\x8c♦l`☻\x90↕↕nn
$`☻☻nr\x8e\x92\x92n

rr\x92`☻p\xf2n►☻

r\x8c∟∟b
♦☻
b
n\xe2n
♦
b\xc4\xf2nn'
♦l`☻\x90↕↕nn
$`☻☻nr\x8e\x92\x92n

r↕l`☻r\x92\x92n

r↕l`☻\x9c☻

\xec♦r

l`☻\xfc\x82n\x92`☻[I][logger:258]: Log initialized
[20:58:05][C][ota:469]: There have been 0 suspected unsuccessful boot attempts.
[20:58:05][I][app:029]: Running through setup()...
[20:58:05][I][i2c.arduino:175]: Performing I2C bus recovery
[20:58:05][D][template.switch:050]:   Restored state OFF
[20:58:05][D][switch:017]: 'TagReader Buzzer Enabled' Turning OFF.
[20:58:05][D][switch:037]: 'TagReader Buzzer Enabled': Sending state OFF
[20:58:05][D][template.switch:050]:   Restored state OFF
[20:58:05][D][switch:017]: 'TagReader LED enabled' Turning OFF.
[20:58:05][D][switch:037]: 'TagReader LED enabled': Sending state OFF
[20:58:05][C][esp8266_pwm:017]: Setting up ESP8266 PWM Output...
[20:58:05][C][light:036]: Setting up light 'TagReader LED'...
[20:58:05][D][light:035]: 'TagReader LED' Setting:
[20:58:05][D][light:040]:   Color mode: RGB
[20:58:05][D][light:084]:   Transition length: 1.0s
[20:58:05][C][pn532:018]: Setting up PN532...
[20:58:05][E][pn532:022]: Error sending version command
[20:58:05][E][component:113]: Component pn532 was marked as failed.
[20:58:05][D][binary_sensor:034]: 'TagReader Status': Sending initial state OFF
[20:58:05][D][text_sensor:067]: 'TagReader ESPHome Version': Sending state '2022.11.1'
[20:58:05][C][wifi:037]: Setting up WiFi...
[20:58:05][C][wifi:038]:   Local MAC: C8:C9:A3:0A:CD:F7
[20:58:05][D][wifi:048]: Loaded saved wifi settings: Wifi PopMoutHouse
[20:58:05][D][wifi:386]: Starting scan...
[20:58:11][D][wifi:401]: Found networks:
[20:58:11][I][wifi:444]: - 'Wifi PopMoutHouse' (80:CC:9C:47:D7:DD) ▂▄▆█
[20:58:11][D][wifi:446]:     Channel: 1
[20:58:11][D][wifi:447]:     RSSI: -72 dB
[20:58:11][D][wifi:449]: - 'DaikinAP17331' (C4:AC:59:C5:6D:97) ▂▄▆█
[20:58:11][D][wifi:449]: - 'DaikinAP06739' (C4:AC:59:C5:63:3F) ▂▄▆█
[20:58:11][D][wifi:449]: - 'Bbox-9F32E9B4' (F0:4D:D4:17:F5:70) ▂▄▆█
[20:58:11][D][wifi:449]: - 'FreeWifi_secure' (E4:9E:12:10:9E:F3) ▂▄▆█
[20:58:11][D][wifi:449]: - 'Freebox-109EF1' (E4:9E:12:10:9E:F2) ▂▄▆█
[20:58:11][D][wifi:449]: - 'Bbox-6ABBD6F0' (84:1E:A3:AE:51:F0) ▂▄▆█
[20:58:11][I][wifi:257]: WiFi Connecting to 'Wifi PopMoutHouse'...
[20:58:13][I][wifi:518]: WiFi Connected!
[20:58:13][C][wifi:362]:   Local MAC: C8:C9:A3:0A:CD:F7
[20:58:13][C][wifi:363]:   SSID: 'Wifi PopMoutHouse'
[20:58:13][C][wifi:364]:   IP Address: 192.168.1.35
[20:58:13][C][wifi:365]:   BSSID: 80:CC:9C:47:D7:DD
[20:58:13][C][wifi:367]:   Hostname: 'tagreader-0acdf7'
[20:58:13][C][wifi:369]:   Signal strength: -78 dB ▂▄▆█
[20:58:13][C][wifi:373]:   Channel: 1
[20:58:13][C][wifi:374]:   Subnet: 255.255.255.0
[20:58:13][C][wifi:375]:   Gateway: 192.168.1.1
[20:58:13][C][wifi:376]:   DNS1: 192.168.1.1
[20:58:13][C][wifi:377]:   DNS2: 0.0.0.0
[20:58:13][D][wifi:527]: Disabling AP...
[20:58:13][C][ota:093]: Over-The-Air Updates:
[20:58:13][C][ota:094]:   Address: tagreader.local:8266
[20:58:13][C][api:025]: Setting up Home Assistant API server...
[20:58:13][I][app:062]: setup() finished successfully!
[20:58:13][D][text_sensor:067]: 'TagReader Connected SSID': Sending state 'Wifi PopMoutHouse'
[20:58:13][D][text_sensor:067]: 'TagReader IP Address': Sending state '192.168.1.35'
[20:58:13][I][app:102]: ESPHome version 2022.11.1 compiled on Nov 18 2022, 20:57:07
[20:58:13][I][app:104]: Project adonno.tag_reader version 1.4
[20:58:13][C][wifi:504]: WiFi:
[20:58:13][C][wifi:362]:   Local MAC: C8:C9:A3:0A:CD:F7
[20:58:13][C][wifi:363]:   SSID: 'Wifi PopMoutHouse'
[20:58:13][C][wifi:364]:   IP Address: 192.168.1.35
[20:58:13][C][wifi:365]:   BSSID: 80:CC:9C:47:D7:DD
[20:58:13][C][wifi:367]:   Hostname: 'tagreader-0acdf7'
[20:58:13][C][wifi:369]:   Signal strength: -78 dB ▂▄▆█
[20:58:13][C][wifi:373]:   Channel: 1
[20:58:13][C][wifi:374]:   Subnet: 255.255.255.0
[20:58:13][C][wifi:375]:   Gateway: 192.168.1.1
[20:58:13][C][wifi:376]:   DNS1: 192.168.1.1
[20:58:13][C][wifi:377]:   DNS2: 0.0.0.0
[20:58:13][C][logger:293]: Logger:
[20:58:13][C][logger:294]:   Level: DEBUG
[20:58:13][C][logger:295]:   Log Baud Rate: 115200
[20:58:13][C][logger:296]:   Hardware UART: UART0
[20:58:13][C][i2c.arduino:052]: I2C Bus:
[20:58:13][C][i2c.arduino:053]:   SDA Pin: GPIO4
[20:58:13][C][i2c.arduino:054]:   SCL Pin: GPIO5
[20:58:13][C][i2c.arduino:055]:   Frequency: 400000 Hz
[20:58:13][C][i2c.arduino:058]:   Recovery: bus successfully recovered
[20:58:13][C][template.switch:058]: Template Switch 'TagReader Buzzer Enabled'
[20:58:13][C][template.switch:058]:   Icon: 'mdi:volume-high'
[20:58:13][C][template.switch:059]:   Restore State: YES
[20:58:13][C][template.switch:060]:   Optimistic: YES
[20:58:13][C][template.switch:058]: Template Switch 'TagReader LED enabled'
[20:58:13][C][template.switch:058]:   Icon: 'mdi:alarm-light-outline'
[20:58:13][C][template.switch:059]:   Restore State: YES
[20:58:13][C][template.switch:060]:   Optimistic: YES
[20:58:13][C][esp8266_pwm:022]: ESP8266 PWM:
[20:58:13][C][esp8266_pwm:023]:   Pin: GPIO13
[20:58:13][C][esp8266_pwm:024]:   Frequency: 1000.0 Hz
[20:58:13][C][light:104]: Light 'TagReader LED'
[20:58:13][C][light:106]:   Default Transition Length: 1.0s
[20:58:13][C][light:107]:   Gamma Correct: 2.80
[20:58:13][C][restart.button:017]: Restart Button 'TagReader Restart'
[20:58:13][C][pn532:347]: PN532:
[20:58:13][C][pn532:359]:   Update Interval: 1.0s
[20:58:13][C][pn532_i2c:128]:   Address: 0x24
[20:58:13][C][status:034]: Status Binary Sensor 'TagReader Status'
[20:58:13][C][status:034]:   Device Class: 'connectivity'
[20:58:13][C][version.text_sensor:021]: Version Text Sensor 'TagReader ESPHome Version'
[20:58:13][C][version.text_sensor:021]:   Icon: 'mdi:new-box'
[20:58:13][C][rtttl:018]: Rtttl
[20:58:13][C][captive_portal:088]: Captive Portal:
[20:58:13][C][mdns:103]: mDNS:
[20:58:13][C][mdns:104]:   Hostname: tagreader-0acdf7
[20:58:13][C][ota:093]: Over-The-Air Updates:
[20:58:13][C][ota:094]:   Address: tagreader.local:8266
[20:58:13][C][api:138]: API Server:
[20:58:13][C][api:139]:   Address: tagreader.local:6053
[20:58:13][C][api:143]:   Using noise encryption: NO
[20:58:13][C][improv_serial:032]: Improv Serial:
[20:58:13][C][wifi_info:009]: WifiInfo IPAddress 'TagReader IP Address'
[20:58:13][C][wifi_info:009]:   Icon: 'mdi:wifi'
[20:58:13][C][wifi_info:011]: WifiInfo SSID 'TagReader Connected SSID'
[20:58:13][C][wifi_info:011]:   Icon: 'mdi:wifi-strength-2'
[21:03:05][I][ota:113]: Boot seems successful, resetting boot loop counter.
[21:09:45][D][api:102]: Accepted 192.168.1.30
[21:09:45][D][main:414]: API is connected!
[21:09:45][D][rtttl:038]: Playing song success
[21:09:45][D][light:035]: 'TagReader LED' Setting:
[21:09:45][D][light:046]:   State: ON
[21:09:45][D][light:050]:   Brightness: 100%
[21:09:45][D][light:057]:   Red: 0%, Green: 0%, Blue: 100%
[21:09:45][D][light:077]:   Flash length: 0.5s
[21:09:45][D][switch:013]: 'TagReader Buzzer Enabled' Turning ON.
[21:09:45][D][switch:037]: 'TagReader Buzzer Enabled': Sending state ON
[21:09:45][D][switch:013]: 'TagReader LED enabled' Turning ON.
[21:09:45][D][switch:037]: 'TagReader LED enabled': Sending state ON
[21:09:45][D][binary_sensor:036]: 'TagReader Status': Sending state ON
[21:09:45][D][api.connection:917]: ESPHome Logs 2022.11.1 (192.168.1.30): Connected successfully
[21:09:45][I][app:102]: ESPHome version 2022.11.1 compiled on Nov 18 2022, 20:57:07
[21:09:45][I][app:104]: Project adonno.tag_reader version 1.4
[21:09:45][C][wifi:504]: WiFi:
[21:09:45][C][wifi:362]:   Local MAC: C8:C9:A3:0A:CD:F7
[21:09:45][C][wifi:363]:   SSID: 'Wifi PopMoutHouse'
[21:09:45][C][wifi:364]:   IP Address: 192.168.1.35
[21:09:45][C][wifi:365]:   BSSID: 80:CC:9C:47:D7:DD
[21:09:45][C][wifi:367]:   Hostname: 'tagreader-0acdf7'
[21:09:45][C][wifi:369]:   Signal strength: -76 dB ▂▄▆█
[21:09:45][C][wifi:373]:   Channel: 1
[21:09:45][C][wifi:374]:   Subnet: 255.255.255.0
[21:09:45][C][wifi:375]:   Gateway: 192.168.1.1
[21:09:45][C][wifi:376]:   DNS1: 192.168.1.1
[21:09:45][C][wifi:377]:   DNS2: 0.0.0.0
[21:09:45][C][logger:293]: Logger:
[21:09:45][C][logger:294]:   Level: DEBUG
[21:09:45][C][logger:295]:   Log Baud Rate: 115200
[21:09:45][C][logger:296]:   Hardware UART: UART0
[21:09:45][C][i2c.arduino:052]: I2C Bus:
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
adonno, 2022-11-18:
Your issue is here, 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

Can you upload picture from your soldering?

Elmout33, 2022-11-18:
Here pictures.

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

Elmout33, 2022-11-19:
Hi @adonno, I make the real solidering (yesterday just for test I just plug the component whitout soldering).

My error message disappear :) and my tag are now detected in Home Assistant !
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

Thanks a lot for your quick answer !

Closed 2022-11-19.

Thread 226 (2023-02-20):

Can't read NFC-Tags

BjGoCraft, 2023-02-20:
Hi,
Everything is connected right (I tested every connection with a multimeter). The switch 1 on the reader module is on (up) and switch 2 off:
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

The ESP is shown in HomeAssistant as a device of the service ESPHome. So the ESP is recognized. I once connected a LED to it and I could control it with the TagReaderLED switch within Home Assistant, so HomeAssistant can communicate with the ESP. But when I put a NFC-Card on the reader, there is no event in the logbook. The NFC-Card works fine with my smartphone (it's the one the Reader came with).

bbrendon, 2023-03-26:
I was running a very old version of this project and mine was working until today when I updated it because I didn't have the LED and Buzzer enabled.

For me, the esphome appears in hass but like you, the NFC reader no longer works. I'm not sure what specifically the issue is yet. I'm still trying to work it out.

BjGoCraft, 2023-03-26:
For me it turned out to be bad soldering. Even though I checked every connection with a multimeter, resoldering the NFC-Reader to the cables did the job for me.

bbrendon, 2023-03-26:
After some closer looking, mine is wired completely different. It looks like a lot has changed since I built mine. So I guess I find old firmware or re-wire it.

chernerd, 2023-11-17:
@BjGoCraft when you re-soldered did you have to remove the jumper pins and directly solder the wires? How did you resolder?

Closed 2023-03-26.

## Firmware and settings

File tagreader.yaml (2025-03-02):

# Insert your SSID and Your PWD after inital setup
wifi:
# networks:
#    - ssid: 'REPLACEME'          # Enter your WiFi SSID here. Example: `ssid: 'your_network_name'`
#      password: 'REPLACEME'      # Enter your wifi password here. Example: `password: 'abcde123456'`
  ap:
    ssid: ${name}

# Enable the captive portal for inital WiFi setup
captive_portal:

dashboard_import:
  package_import_url: github://adonno/tagreader/tagreader.yaml

improv_serial:


substitutions:
  name: tagreader
  friendly_name: TagReader

esp8266:
  board: d1_mini

esphome:
  name: $name

  # Automatically add the mac address to the name
  # so you can use a single firmware for all devices
  name_add_mac_suffix: true

  # This will allow for (future) project identification,
  # configuration and updates.
  project:
    name: adonno.tag_reader
    version: dev
# If buzzer is enabled, notify on api connection success
  on_boot:
    priority: -10
    then:
    - wait_until:
        api.connected:
    - logger.log: API is connected!
    - rtttl.play: "success:d=24,o=5,b=100:c,g,b"
    - light.turn_on:
        id: activity_led
        brightness: 100%
        red: 0%
        green: 0%
        blue: 100%
        flash_length: 500ms
    - switch.turn_on: buzzer_enabled
    - switch.turn_on: led_enabled

# Define switches to control LED and buzzer from HA
switch:
- platform: template
  name: "${friendly_name} Buzzer Enabled"
  id: buzzer_enabled
  icon: mdi:volume-high
  optimistic: true
  restore_mode: RESTORE_DEFAULT_ON
  entity_category: config
- platform: template
  name: "${friendly_name} LED enabled"
  id: led_enabled
  icon: mdi:alarm-light-outline
  optimistic: true
  restore_mode: RESTORE_DEFAULT_ON
  entity_category: config

# Define buttons for writing tags via HA
button:
  - platform: template
    name: Write Tag Random
    id: write_tag_random
    # Optional variables:
    icon: "mdi:pencil-box"
    on_press:
      then:
      - light.turn_on:
          id: activity_led
          brightness: 100%
          red: 100%
          green: 0%
          blue: 100%
      - lambda: |-
          static const char alphanum[] = "0123456789abcdef";
          std::string uri = "https://www.home-assistant.io/tag/";
          for (int i = 0; i < 8; i++)
            uri += alphanum[random_uint32() % (sizeof(alphanum) - 1)];
          uri += "-";
          for (int j = 0; j < 3; j++) {
            for (int i = 0; i < 4; i++)
              uri += alphanum[random_uint32() % (sizeof(alphanum) - 1)];
            uri += "-";
          }
          for (int i = 0; i < 12; i++)
            uri += alphanum[random_uint32() % (sizeof(alphanum) - 1)];
          auto message = new nfc::NdefMessage();
          message->add_uri_record(uri);
          ESP_LOGD("tagreader", "Writing payload: %s", uri.c_str());
          id(pn532_board).write_mode(message);
      - rtttl.play: "write:d=24,o=5,b=100:b"
      - wait_until:
          not:
            pn532.is_writing:
      - light.turn_off:
          id: activity_led
      - rtttl.play: "write:d=24,o=5,b=100:b,b"
  - platform: template
    name: Clean Tag
    id: clean_tag
    icon: "mdi:nfc-variant-off"
    on_press:
      then:
      - light.turn_on:
          id: activity_led
          brightness: 100%
          red: 100%
          green: 64.7%
          blue: 0%
      - lambda: 'id(pn532_board).clean_mode();'
      - rtttl.play: "write:d=24,o=5,b=100:b"
      - wait_until:
          not:
            pn532.is_writing:
      - light.turn_off:
          id: activity_led
      - rtttl.play: "write:d=24,o=5,b=100:b,b"
  - platform: template
    name: Cancel writing
    id: cancel_writing
    icon: "mdi:pencil-off"
    on_press:
      then:
      - lambda: 'id(pn532_board).read_mode();'
      - light.turn_off:
          id: activity_led
      - rtttl.play: "write:d=24,o=5,b=100:b,b"

  - platform: restart
    name: "${friendly_name} Restart"
    entity_category: config
# Enable logging
logger:
  # level: VERY_VERBOSE
  # level: VERBOSE
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

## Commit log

2020-09-14 Adding STLs for 3D-printing the case and lid
    [Case-2.stl, Cover-circles_horizontal.stl, Cover-circles_vertical.stl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]
2020-09-15 Using PCB naming convention for ease of use
2020-09-15 Add photo of open case
2020-09-15 Add schematics picture and project
    [Tag Reader Schematics.fzz]
2020-09-15 Add correct schematics picture
2020-09-15 Fixx correct schematics picture in Readme
2020-09-17 Removing deprecated text sensor
2020-09-17 Optimize tagreader.yaml (#9)
    * Optimize the tagreader.yaml
    * Fixed if
    * Consistent indentation
    [tagreader.yaml]
2020-09-17 Remove `webserver` (#11)
    We don't need the webserver and should try to conserve memory and power usage
2020-09-18 Revert icon for buzzer switch
    [tagreader.yaml]
2020-09-18 Expose LED to Home Assistant Also flash the led on a tag scan
2020-09-18 Better flow for setting up wifi
2020-09-18 Documenting the DIP-switches on PN532
2020-09-19 Add BMAC-button for Andrea
2020-09-19 Change ap ssid to devicename Remove comments suggesting to delete the `ap`
2020-09-20 Swapping TX-pin for D0.
    [tagreader.yaml]
2020-09-21 Change board to be a substitution
2020-09-21 Revert "Change board to be a substitution"
    [tagreader.yaml]
2020-09-21 Updating Fritzing project to latest version
    [Tag Reader Schematics.fzz]
2020-09-23 Add Cover without Home Assistant logo
    [Cover-circles_no_logo.stl]
2020-09-30 Update README.md
    Added Warning for AZdelivery board
    removed "wemos" definition since it seems practically impossible to find them anywhere
2020-10-11 Updated schematics project for I2C/5V
    I2C-version of the schematics screenshot
    Delete tag_reader_schematics_v1.png
    Update README.md
    Using relative links for schematics screenshot
    [Tag Reader Schematics.fzz]
2020-10-11 Switch the switches
2020-12-15 Added restore_state to the switches
    Added restore_state: true to both the Buzzer switch and the LED switch so the user doesn't have to create an automaton just to keep the visual and audible feedback on.
    [tagreader.yaml]
2021-01-03 Default the Buzzer and LED to enabled
    on startup enable the busser and the LED. I made this change to my reader after noticing that the restore state dose does not work most of the time. Defaulting to enabled comes from feedback from noticing the tag users scanning the tag more than ones thinking that the tag was not scanned.
    [tagreader.yaml]
2021-01-10 Tag Reader Schematics v3
    Revised Fritzing diagram - inverted incorrect tx/rx cables. Simplied and tidied up.
    [Tag Reader Schematics v3.fzz]
2021-01-10 Inside case completed
    Updated image of inside case - easier to read and tested working ok
2021-01-10 Tag Read Schematics v3 image
    Improved PNG image of Tag Read Schematics. Based on uploaded Fritzing image. Manually edited image labels on LED to match one being shipped by Adonno. also have DIP switches in correct position to help with users. Also inverted TX/RX which appear to be incorrect in current image.
2021-01-10 Delete Tag Reader Schematics v3.png
    deleting to update file name
2021-01-10 updated schematics image
    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
2021-01-17 updated schematics image from feedback 20210117 RC
2021-01-17 Tag Reader Schematics v3 (fritzing file)
    Open file using https://www.fritzing.org
    [Tag Reader Schematics v3.1.fzz]
2021-01-20 Tag Reader Schematics v3.2 (fritzing file)
    For more info on opening file, visit https://www.fritzing.org/
    [Tag Reader Schematics v3.2.fzz]
2021-01-20 updated schematics image
    updated schematics image from feedback 20210120 RC
2021-01-20 update image link for schematics
2021-01-20 updated schematics image
2021-01-20 updated schematics png
    updated schematics image to accompany fzz file
2021-02-03 Remove continuous as it had an issue
    [tagreader.yaml]
2021-05-04 Cleaning tag=orange LED, writing tag=red LED
    Orange led when cleaning tag, red light when writing, and turns off when done :)
2021-09-20 Update tagreader.yaml
    Remove a line due to change in ESPHome that would turn on the LED and leave it on all time
2021-10-05 Fix LLED always on
    After some trial and thanks to @tdroza the issue is now reolved
    [tagreader.yaml]
2021-11-18 Update for ESPHome 2021.11
    Adapted to
    ➕ add Imrpov _serial
    ➕ add Entity categories
    ➕ add network diagnostics
    ➕ dashboard import. With this version on tag reader will automatically pull the newest updated version of the YAML from Github every 24h https://esphome.io/changelog/2021.10.0.html#dashboard-node-imp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
2022-01-27 Add Button to replace services
    Adding button for Writing/ erasing tags to simplify the usability of the tag reader
    [tagreader.yaml]
2022-01-27 fix naming for restart button
    [tagreader.yaml]
2022-02-17 replace FasLED by neopixelbus
    FastLED does not work as expected with Arduino 3 or newer for ESP8266 in ESPHome.
    [tagreader.yaml]
2022-03-12 fix neopixelbus stability issues with delay
    delay 0.1s fixes neopixelbus stabiity
    [15:43:59][V][component:199]: Component pn532 took a long time for an operation (0.11 s).
    [15:43:59][V][component:200]: Components should block for at most 20-30ms.
    [tagreader.yaml]
2023-07-21 :bug: Changed LED to RESTORE_DEFAULT_ON
    [tagreader.yaml]
2024-06-20 fix ota issue in esphome
    https://github.com/esphome/esphome/pull/6459
    this change ^
    [tagreader.yaml]
